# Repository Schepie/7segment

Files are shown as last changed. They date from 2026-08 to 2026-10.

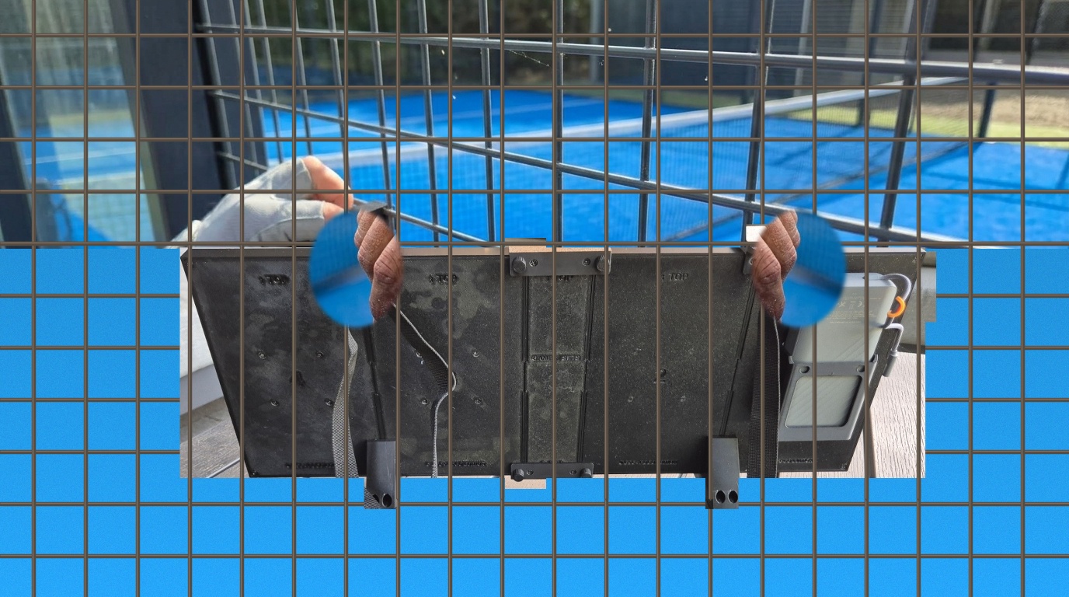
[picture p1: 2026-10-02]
scratch_hanging_proposal.jpg

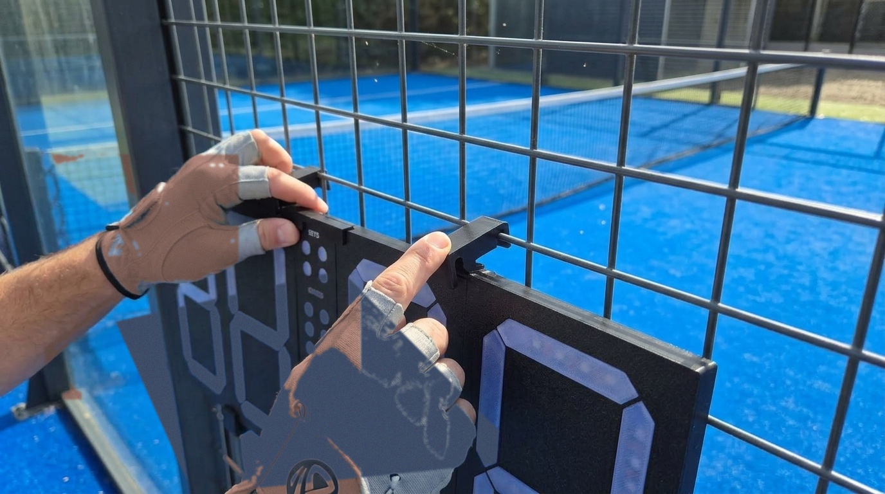
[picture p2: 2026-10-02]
scratch_hang_test.jpg

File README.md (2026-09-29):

# 🎾 ESP32 7-Segment Padel Scoreboard & Digital Clock

A professional, modular, high-visibility electronic scoreboard and real-time clock system built with **ESP32**, **WS2813 addressable LEDs (dual-signal backup line, up to 136 LEDs)**, **Bluetooth Low Energy (BLE)**, **Web Bluetooth API**, and snap-fit 3D-printed 7-segment displays.

The scoreboard acts as the **Master Rules Engine** and single source of truth for the entire match ecosystem, synchronizing in real time with the **Wear OS smartwatch app**, a physical **Xiaomi Bluetooth clicker remote**, and the **companion spectator mobile web app**.

📊 **Interactive Development Presentation Deck:** Open [**`presentation.html`**](presentation.html) in your browser (or view the [Presentation Notes](PRESENTATION.md)) for an interactive slide-by-slide walkthrough detailing how the hardware, 3D CAD, firmware SPI DMA drivers, and companion web apps were built.

---

## 🌟 System Architecture & Master/Slave Model

In this ecosystem, the **ESP32 Scoreboard is ALWAYS the Master**. It maintains and enforces all match rules, points, games, sets, and tiebreaks:

```
                  ┌─────────────────────────────────────────────────────────┐
                  │                 ESP32 SCOREBOARD MASTER                 │
                  │   (src/main_button_Setsandmatch.cpp / NVS Flash Cfg)    │
                  └───────────────┬─────────────────────────┬───────────────┘
                                  │                         │
                  BLE GATT Server │                         │ BLE Central (HID)
          ("Padel Display" 0x4FAF)│                         │ (Auto-Pairing)
                                  ▼                         ▼
         ┌─────────────────────────────────┐       ┌────────────────────────┐
         │     WEAR OS SMARTWATCH SLAVE    │       │  XIAOMI SHUTTER REMOTE │
         │   • Syncs rules via CMD,REQ     │       │    (XYLY01 Clicker)    │
         │   • Touch & voice point scoring │       │  • Big Btn: Team 1 (Pt)│
         │   • NFC & QR spectator sharing  │       │  • Sml Btn: Team 2 (Pt)│
         └────────────────┬────────────────┘       │  • Dbl Click: UNDO     │
                          │                        └────────────────────────┘
                          │ HTTPS REST
                          │ (Netlify Functions)
                          ▼
         ┌─────────────────────────────────┐
         │     SPECTATOR WEB APP SLAVE     │
         │   (https://padelpunten.netlify) │
         │   • Real-time match observer    │
         │   • Read-only rules display     │
         │   • Single Team Focus modes     │
         └─────────────────────────────────┘
```

* **Master Rules Enforcement:** Match rules (Golden Point vs. Advantage, Best of 3 sets vs. 1 set, 6 vs. 9 games per set, Tiebreak) are stored in ESP32 Non-Volatile Flash (`NVS`) and transmitted to clients on connect via `CFG,...`. Clients cannot alter rules during play.
* **Slave Synchronization:** The Wear OS app and spectator web app act as clients. They receive configuration broadcasts and mirror the official master state.
* **Web Bluetooth Direct Control:** Court administrators can configure match rules, brightness, sleep timeouts, and RTC time directly via the [Scoreboard Mobile Controller](https://schepie.github.io/7segment/settings.html).

---

## 🎨 Unified Team Color Standard

To avoid confusion between players, spectators, and hardware displays, all components adhere strictly to this unified color mapping:

| Component | Team 1 (Left / Serving) | Team 2 (Right / Receiving) | Sets Indicator |
| :--- | :---: | :---: | :---: |
| **Color** | **BLUE** | **RED** | **GOLD / YELLOW** |
| **ESP32 WS2813 RGB** | `RGB(0, 180, 255)` | `RGB(255, 0, 0)` | `RGB(255, 180, 0)` |
| **Web Controller (`settings.html`)** | `#00d2ff` | `#ff3366` | `#ffb300` |
| **Wear OS Watch App** | `#1E88E5` | `#E53935` | `#FFB300` |
| **Spectator Mobile Web App** | `#3b82f6` | `#ef4444` | `#eab308` |
| **Xiaomi Remote Button** | **Big Button (Top / Shutter)** | **Small Button (Bottom / Mode)** | N/A |
| **Physical Display Position** | **Digits 0 & 1 (Left)** | **Digits 2 & 3 (Right)** | **Middle Module (LEDs 56..79)** |

---

## 📖 Firmware Editions & Programs

All firmware source files reside in [`src/`](src/) and can be compiled using PlatformIO:

### 1. Flagship: Sets & Match Dual-Role Edition — [src/main_button_Setsandmatch.cpp](src/main_button_Setsandmatch.cpp) *(Recommended)*
The ultimate tournament firmware with simultaneous multi-device connectivity and dedicated Games & Sets indicators:
* **Simultaneous Connections:** Operates as a **BLE Central** (connected to the Xiaomi Remote clicker) **AND** a **BLE Peripheral** (advertising as `"Padel Display"` for the Wear OS watch and web controller).
* **24-LED Games & Sets Module (LEDs 56..79):**
  * Left column (Team 1 Blue): 9 Game LEDs (bottom-to-top) + 2 Set LEDs.
  * Right column (Team 2 Red): 2 Set LEDs + 9 Game LEDs (top-to-bottom).
* **Hardware SPI DMA Driver (ESP32-C3):** Pushes WS2813 bitstreams via hardware SPI MOSI (`GPIO 2`) with DMA buffering. Completely immune to BLE radio interrupts, preemption, or flicker. Features >= 280us LOW reset pulse timing and dual-signal line compatibility.
* **NVS Flash Persistence (`padel_cfg`):** Remembers match settings, LED brightness, idle timeouts, and paired remote MAC across power cuts.
* **Inactivity Idle Timer:** Automatically fades to Digital Clock mode after a configurable idle period (e.g. 5 minutes without activity).
* **Official Rules Engine:**
  * Advantage (`Ad`) vs. Golden Point / Punto de Oro (`GP`).
  * Sets to win (1 or 2).
  * Games per set (6 or 9).
  * Tiebreak mode at 6-6 (or 8-8) with alternating court side-swap tracking.
  * 30-step historical Undo buffer.
* **End-of-Match Celebration:** Victory animations (`GAmE`) and automated cycling through past set scores (`6-4`, `3-6`, `7-6`).

### 2. Unified 3-in-1 Firmware — [src/main_combined.cpp](src/main_combined.cpp)
Cycle between 3 distinct modes using a single onboard push-button (**BOOT** button on `GPIO 9` or `GPIO 0`):
* **Mode 0: Digital Clock (`CLOC`):** Displays 24-hour real-time clock synced via DS1302 RTC or computer build time.
* **Mode 1: BLE Padel Scoreboard (`SCOR`):** Standard BLE GATT server.
* **Mode 2: Xiaomi Shutter Remote Scoreboard (`ShUt`):** Direct BLE Central clicker connection.

### 3. Standalone Programs
* **[src/main_clock.cpp](src/main_clock.cpp):** Lightweight dedicated digital wall clock with smooth 6-second color crossfades.
* **[src/main.cpp](src/main.cpp):** Dedicated BLE GATT peripheral receiver.
* **[src/main_button.cpp](src/main_button.cpp):** Standalone Xiaomi remote clicker receiver (4 digits only).
* **[src/main_dual_4digits.cpp](src/main_dual_4digits.cpp):** Simultaneous remote + BLE watch connection without middle LED module.

---

## 📱 Web Bluetooth Controller & Settings App

Control the scoreboard directly from any smartphone, tablet, or laptop browser (Chrome, Edge, Bluefy) without installing an app:

🔗 **Live Controller URL:** [https://schepie.github.io/7segment/settings.html](https://schepie.github.io/7segment/settings.html)

### Features:
1. **Court Tab:** Live mirrored score digits, quick scoring buttons (+1 Team 1 Blue, +1 Team 2 Red), Undo, Reset Match, Court Side Swap, and Mode Switch (Clock / Scoreboard).
2. **Display Tab:** Real-time brightness slider (0..255), auto-sleep / idle timeout selector (Never, 1m, 5m, 10m, 15m, 30m), and one-tap **Sync Phone Time** button (sets the DS1302 RTC to local browser time).
3. **Rules Tab (Master Config):** Set Golden Point, Sets to Win (1 vs 3), Games per Set (6 vs 9), and Tiebreak rules. Automatically saves to ESP32 Flash memory and notifies connected smartwatches.
4. **Offline PWA Support:** Add to your mobile home screen with high-resolution icons for instant court-side launching.

---

## 📷 Xiaomi / YI Bluetooth Remote Controls (XYLY01)

The scoreboard connects directly to the Xiaomi / YI Action Camera Remote (`XiaoYi_RC`) over BLE HID (Characteristic `0x2A4D` under Service `0x1812`).

```
           ┌────────────────────────┐
           │        (  ○  )         │  <--- BIG BUTTON (0x40)
           │      Top Shutter       │       • Single Click: +1 Point Team 1 (Left / Blue)
           │                        │       • Double Click: UNDO Previous Point
           │                        │
           │        [  ■  ]         │  <--- SMALL BUTTON (0x80)
           │      Bottom Mode       │       • Single Click: +1 Point Team 2 (Right / Red)
           │                        │       • Double Click: UNDO Previous Point
           └────────────────────────┘
```

* **Single Click:**
  * **Big Button:** Adds a point to **Team 1 (Blue)** (` 0` $\to$ `15` $\to$ `30` $\to$ `40` $\to$ `Ad` $\to$ Game Won).
  * **Small Button:** Adds a point to **Team 2 (Red)**.
* **Double Click (Either Button within 380ms):**
  * Reverts the match state to the previous point, game, or set from the 30-entry history stack.
* **Auto-Pairing:** The ESP32 scans for `XiaoYi_RC`, pairs automatically, and persists the MAC address to NVS flash for instant reconnects on startup.

---

## 📡 Bluetooth Low Energy (BLE) Protocol Specification

The ESP32 runs a BLE GATT Server advertising as `"Padel Display"`.

### GATT Identifiers:
* **Device Name:** `Padel Display`
* **GATT Service UUID:** `4fafc201-1fb5-459e-8fcc-c5c9c331914b`
* **GATT Characteristic UUID:** `beb5483e-36e1-4688-b7f5-ea07361b26a8`
* **Client Characteristic Configuration (CCCD):** `00002902-0000-1000-8000-00805f9b34fb` (Enable notifications: `0x0001`)

### Packet Formats:

#### 1. Configuration Broadcast (`CFG,...`)
Sent automatically upon client connection, or in response to `CMD,REQ_CFG`:
```
"CFG,GP=0,SETS=2,GAMES=6,TB=1,BRT=180,IDLE=300000"
      │    │      │       │    │       └── Inactivity idle timeout in ms (300000 = 5 min)
      │    │      │       │    └────────── LED Brightness (0 - 255)
      │    │      │       └─────────────── Tiebreak Enabled (1 = Yes, 0 = No)
      │    │      └─────────────────────── Games per Set (6 or 9)
      │    └────────────────────────────── Sets to Win (1 = Single set, 2 = Best of 3)
      └─────────────────────────────────── Golden Point (1 = Punto de Oro, 0 = Advantage)
```
Clients can write this string to update and persist rules into ESP32 flash.

#### 2. Live Score Notification (`SCORE,...`)
Notified whenever points, games, sets, or court sides change:
```
"1530,0,1,2,0,0,0"
 │ │ │ │ │ │ │ └── In Tiebreak Mode (0 = Normal, 1 = Tiebreak active)
 │ │ │ │ │ │ └──── Team 2 Sets Won
 │ │ │ │ │ └────── Team 1 Sets Won
 │ │ │ │ └──────── Team 2 Games Won
 │ │ │ └────────── Team 1 Games Won
 │ │ └──────────── Court Side Swapped Flag (0 = Normal, 1 = Swapped ends)
 │ └────────────── Team 2 Points (" 0", "15", "30", "40", "Ad")
 └──────────────── Team 1 Points (" 0", "15", "30", "40", "Ad")
```
*In Tiebreak mode*, points represent tiebreak rally points: `" 4 3,0,6,6,1,1,1"`.

#### 3. Control Commands (`CMD,...`)
Written by clients (Watch or Web Controller) to trigger actions:
* `CMD,P1`: Increment point for Team 1 (Blue).
* `CMD,P2`: Increment point for Team 2 (Red).
* `CMD,UNDO`: Step back one state in history.
* `CMD,RESET`: Reset the match to 0-0.
* `CMD,SWAP`: Manually toggle court side display orientation.
* `CMD,CLOCK`: Force the display into Digital Clock mode.
* `CMD,SCORE`: Wake up display into Scoreboard mode.
* `CMD,REQ` / `CMD,REQ_CFG`: Request the ESP32 to immediately notify current configuration and score.

#### 4. Time Synchronization (`TIME,...`)
Written by `settings.html` to calibrate the onboard DS1302 RTC:
```
"TIME,14:35:00"
```

---

## 🔌 Hardware Wiring & Pinout

### 1. LED Chain Routing (136 LEDs Total)
One continuous data line connects all modules in series:

```
ESP32 DIN (GPIO 2) ──> [ Digit 0 ] ──> [ Digit 1 ] ──> [ Games & Sets ] ──> [ Digit 2 ] ──> [ Digit 3 ]
                       (28 LEDs)       (28 LEDs)       (24 LEDs)            (28 LEDs)       (28 LEDs)
                       LEDs 0..27      LEDs 28..55     LEDs 56..79          LEDs 80..107    LEDs 108..135
                       Team 1 Tens     Team 1 Ones     Middle Module        Team 2 Tens     Team 2 Ones
```

### 2. Segment Wiring per Digit (4 LEDs $\times$ 7 segments = 28 LEDs)
* **Standard Digits (Digits 1, 2, 3):**
  * Segment 0 (BL - Bottom-Left): LEDs `0..3`
  * Segment 1 (B  - Bottom): LEDs `4..7`
  * Segment 2 (BR - Bottom-Right): LEDs `8..11`
  * Segment 3 (M  - Middle): LEDs `12..15`
  * Segment 4 (TL - Top-Left): LEDs `16..19`
  * Segment 5 (T  - Top): LEDs `20..23`
  * Segment 6 (TR - Top-Right): LEDs `24..27`
* **Digit 0 Hardware Variation (`PANEL0_CUSTOM_WIRING`):**
  * Handled automatically in firmware mapping (`panel0SegmentMap`): Slot 0=`TR`, Slot 1=`T`, Slot 2=`TL`, Slot 3=`M`, Slot 4=`BR`, Slot 5=`B`, Slot 6=`BL`.

### 3. Games & Sets Indicator Module (LEDs 56..79)
* **Left Column (Team 1 Blue, bottom to top):**
  * LEDs 56..64 (Indices 0..8): Games G1..G9
  * LED 65 (Index 9): Blank spacer
  * LEDs 66..67 (Indices 10..11): Sets S1..S2
* **Right Column (Team 2 Red, top to bottom):**
  * LEDs 68..69 (Indices 12..13): Sets S2 (top) & S1 (lower)
  * LED 70 (Index 14): Blank spacer
  * LEDs 71..79 (Indices 15..23): Games G9 down to G1

### 4. Microcontroller Pinout Table (ESP32-C3 SuperMini)

| Function | ESP32-C3 SuperMini Pin | Description |
| :--- | :---: | :--- |
| **WS2813 DIN Data Pin** | **`GPIO 2`** | Hardware SPI MOSI (high speed, accurate WS2813 timing) |
| **Status LED** | `GPIO 8` | Blue Onboard LED (Active LOW) |
| **Mode / Boot Button** | `GPIO 9` | Onboard Button / External score control |
| **RTC DS1302 CLK (SCLK)** | `GPIO 4` | Clock line for DS1302 Real-Time Clock module |
| **RTC DS1302 DAT (I/O)** | `GPIO 5` | Bi-directional data line for DS1302 |
| **RTC DS1302 RST (CE)** | `GPIO 3` | Chip enable / reset line for DS1302 |

---

## ⚡ Building & Uploading (PlatformIO)

The project targets the ESP32-C3 SuperMini configured in [`platformio.ini`](platformio.ini):

| Target Microcontroller | Firmware Feature Set | PlatformIO Environment |
| :--- | :--- | :--- |
| **ESP32-C3 SuperMini** | **Flagship (Sets & Match + Module)** | `esp32c3_supermini_button` |

### CLI Build & Flash:
```powershell
# Build and upload flagship firmware to ESP32-C3 SuperMini
pio run -e esp32c3_supermini_button -t upload

# Monitor serial output at 115200 baud
pio device monitor -b 115200
```

---

## 🖨️ 3D Printing Assets (`/scad`)

All enclosure, digit, bracket, and mounting files are open-source OpenSCAD designs:
* `panel_thumbscrew.scad`: **Tool-free M3 thumbscrew knob system** (ergonomic knurled finger knob with anti-spin hex drive lock for M3x12 DIN 7991 countersunk screws and 3.0 mm panel heat-set inserts; 11.2 mm outer diameter engineered specifically for 12.0 mm seam bracket pitch without knob collisions; 100% support-free).
* `display_stand.scad`: **Direct-Mount Desktop Cradle Stand & Seam U-Bracket Replacement** (engineered tabletop stand system with ergonomic 8° backward viewing tilt, compact footprint, and 2x 13.0 mm anti-slip rubber pad recesses; 100% support-free 3D printing):
  * **Direct Panel Mounting (Replaces Bottom U-Bracket):** Standardized to 28.0 mm width with 2x M3 pass-through clearance holes (12.0 mm pitch, 6.0 mm rim inset) drilled directly through the rear spine into the panel backplates' brass heat-set inserts. Because the stand grips both the front lip (11.5 mm) and bolts into the rear backplate, it acts as a rigid bottom U-channel clamping bracket across digit seams ([Digit 1 + Digit 2] or [Digit 3 + Digit 4]), permanently eliminating joint bending while serving as the tabletop foot.
  * **Flush Fastening & Tool Access:** Features DIN 7991 countersink seats (3.2 mm flange thickness matching bracket hardware) and Ø 8.5 mm rear counterbore wells for direct hex-key and screwdriver tool access.
  * **Bolt-on Kickstand Legs:** Alternate rear triangular kickstand legs (`part=4`, `part=5`) for ultra-minimalist prop-up display.
  * STLs: `3d_models/display_stand_cradle_single.stl`, `3d_models/display_stand_cradle_pair.stl`.
* `rear_corner_foot.scad`: Outer corner leveling foot (3.0 mm) ensuring flush, wobble-free table placement across joined rear brackets.
* `rear_joining_bracket_hinged.scad`: Heavy-duty hinged panel-to-panel joining bracket with 3D-printable snap pin (0° to 180° folding).
* `7segment_pogo.scad`: Modular 7-segment digit housings with integrated magnetic pogo pin pockets, diffuser slots, and VESA 50x50 mounts.
* `remote_strap_holder.scad`: Ergonomic clip for wearing the Xiaomi Shutter remote on a wristband or racket lanyard.
* `games_sets_u_bracket.scad`: **Unified 3-Panel U-Profile Bridge Bracket** (continuous 84 mm rigid bridge spanning across the central Games & Sets module and both adjacent digits; U-profile channel clamps both the front face and rear backplate across all 4 M3 corner screw positions to permanently eliminate joint flexing and bending; integrated front-lip cutout provides full clearance for the frontplate "SETS" text; 100% support-free 3D printing; fits both top and bottom rims).
  * STLs: `3d_models/games_sets_u_bracket.stl`, `3d_models/games_sets_u_bracket_pair.stl`.
* `panel_seam_u_bracket.scad`: **2-Panel Digit Seam U-Profile Joining Bracket, Padel Court Hook & Carrying Strap Mount** (rigid 28 mm U-channel bracket clamping across adjacent 7-segment digit panels [Digit 1 + Digit 2] or [Digit 3 + Digit 4] on a 12.0 mm screw pitch; straight square top corners):
  * **Standard Clean U-Bracket** (`part=1`, `part=2`): Clamps top or bottom seam with zero support needed.
  * **Padel Mesh Hook with Top-Facing Strap Eye** (`part=3`, `part=4`, `part=5`): Features the front-facing wire mesh hook (Ø 5.6 mm throat, 16 mm retention lip, 45° entry mouth) with the monolithic triangular carrying strap eye extending vertically upwards from the roof.
  * **Padel Mesh Hook with Rear-Facing Strap Eye** (`part=6`, `part=7`, `part=8`): Features the strap eye extending horizontally **from the back** of the bracket (with dual 45° transition tapers), leaving the top roof 100% flat. The bottom taper terminates at Y = 0 mm, leaving the entire rear flange (Y = 0 to 17 mm) completely flat and open with >6 mm of clearance above the M3 screw centers for effortless screwdriver and Allen key access. Prints flat on its side with 100% continuous perimeter loops and zero support.
  * STLs: `3d_models/panel_seam_u_bracket.stl`, `3d_models/panel_seam_u_hook_bracket.stl`, `3d_models/panel_seam_u_hook_bracket_pair.stl`, `3d_models/panel_seam_u_hook_bracket_rear_eye.stl`, `3d_models/panel_seam_u_hook_bracket_rear_eye_pair.stl`, `3d_models/panel_seam_u_bracket_set4_hook.stl`.
* `games_sets_pogo_snap_individual_dots.scad`: Middle module housing for the 24-LED column array.

---

## 👤 Author
**Geert Schepers**

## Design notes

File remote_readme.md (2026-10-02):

# Xiaomi / YI Bluetooth Remote (XYLY01) Integration Manual

This document details the hardware configuration, Bluetooth Low Energy (BLE) HID communication protocol, button mapping, and 7-segment display driver settings for the **Xiaomi / YI Action Camera Remote (Model: XYLY01 / XiaoYi_RC)** communicating with an **ESP32-C3 SuperMini**.

---

## 1. Hardware Specifications

| Component | Specification |
| :--- | :--- |
| **Microcontroller** | ESP32-C3 SuperMini (RISC-V 160MHz, 4MB Flash, USB CDC on boot) |
| **Bluetooth Remote** | Xiaomi / YI Remote (Model: `XYLY01`, Advertised Name: `XiaoYi_RC`) |
| **Display Panel** | 2x Chained 7-Segment Modules (56 WS2813 LEDs total: 2 digits $\times$ 7 segments $\times$ 4 LEDs) |
| **WS2813 DIN Pin** | **`GPIO 2`** |
| **Onboard Status LED** | **`GPIO 8`** (ESP32-C3 SuperMini onboard LED, active LOW) |
| **LED Index Offset** | **`+1 LED`** (`#define LED_START_OFFSET 1`) for mechanical alignment inside diffusers |

---

## 2. PlatformIO Board Configuration (`platformio.ini`)

The ESP32-C3 SuperMini environment in `platformio.ini`:

```ini
[env:esp32c3_supermini_button]
platform = espressif32
board = esp32-c3-devkitm-1
framework = arduino
build_flags = 
	-DARDUINO_USB_CDC_ON_BOOT=1
	-DARDUINO_USB_MODE=1
lib_deps = 
	adafruit/Adafruit NeoPixel
	h2zero/NimBLE-Arduino @ ^1.4.2
	makuna/RTC @ ^2.4.3
```

---

## 3. BLE HID Communication & Protocol (NimBLE)

### A. Discovery & Identification
- **Supported Remotes:**
  - **Xiaomi / YI Remote (XYLY01):** Advertised Name `XiaoYi_RC`, `XYLY01`
  - **WXLJ-02 & Bluetooth Ring Remotes:** Advertised Names `WXLJ-02`, `WXLJ`, `D01`, `D02`, `Ring`, `Turner`, `Scroller`, `Beauty`
  - **Generic BLE HID Peripherals:** Any BLE peripheral advertising Service UUID `0x1812` or HID Appearance (`0x03C0..0x03C4`).
- **Target Remote MAC Address:** Stored in persistent flash (`padel_remote/remote_mac`) after first pairing for instant auto-reconnect.

### B. Security & Connection Parameters
- The remote operates with **Just Works / Auto-confirm** bonding:
  ```cpp
  NimBLEDevice::init("Padel Display");
  NimBLEDevice::setSecurityAuth(true, true, true); // Bonding + MITM + Secure Connections
  NimBLEDevice::setSecurityIOCap(BLE_HS_IO_NO_INPUT_OUTPUT);
  NimBLEDevice::setPower(ESP_PWR_LVL_P9);
  ```
- **Connection Timing (Prevent Dropouts):**
  ```cpp
  bleClient->setConnectionParams(24, 40, 0, 400); // 30ms - 50ms interval, 4s supervision timeout
  ```
- **Subscribing to HID Notifications:**
  Subscribe to all characteristics with `canNotify()` or `canIndicate()` under Service `0x1812` (particularly Report Characteristic `0x2A4D`) with `pChar->subscribe(true, onHIDNotification, true)`.

---

## 4. Remote Button Packet Structure (XYLY01)

The remote transmits **3-byte notification payloads** to Characteristic `0x2A4D`:

| Button / Action | Raw Notification Bytes | Logic State | Action Triggered |
| :--- | :--- | :--- | :--- |
| **Big Button (Top / Shutter)** | `0x40 0x00 0x00` | Pressed | **Count UP (+1)** |
| **Small Button (Bottom / Mode)** | `0x80 0x00 0x00` | Pressed | **Count DOWN (-1)** |
| **Button Release** | `0x00 0x00 0x00` | Released | Evaluates click count & timing |

---

## 4.B WXLJ-02 & Ring Remote Button Mapping

The WXLJ-02 Bluetooth ring remote features a 3-button layout (Up / Center / Down):

| Button | Supported HID Codes | Scoreboard Function |
| :--- | :--- | :--- |
| **▲ Up Button** | Up Arrow (`0x52`), Page Up (`0x4B`), Volume Up (`0xE9`), Next Track (`0xB5`) | **+1 Point Team 1 (Left / Blue)** |
| **▼ Down Button** | Down Arrow (`0x51`), Page Down (`0x4E`), Volume Down (`0xEA`), Prev Track (`0xB6`) | **+1 Point Team 2 (Right / Red)** |
| **● Center Button** | Return/Enter (`0x28`), Space (`0x2C`), Play/Pause (`0xCD`), Mute (`0xE2`) | **Instant UNDO** (during match)<br>• **Toggle 1st Server** (at 0–0)<br>• **Wake up** (from Clock Mode) |
| **Double Click (▲/▼)** | Within 380ms | **Instant UNDO / Toggle Server** |
| **Long Press (≥1.5s)** | Hold either directional button | **Swap Court Sides** / Toggle Clock |

---

## 5. Interaction & Scoring Controls

```
           ┌────────────────────────┐
           │        (  ○  )         │  <--- BIG BUTTON (0x40)
           │      Top Shutter       │       • Single Click: Count UP (+1)
           │                        │       • Double Click: Next Color
           │                        │
           │        [  ■  ]         │  <--- SMALL BUTTON (0x80)
           │      Bottom Mode       │       • Single Click: Count DOWN (-1)
           │                        │       • Double Click: Next Color
           └────────────────────────┘
```

- **Single Click:**
  - **Big Button:** Increases score from $1 \to 99$.
  - **Small Button:** Decreases score from $99 \to 1$.
- **Double Click (Either Button):**
  - Detected within a **`380ms`** window.
  - Cycles through 8 curated color presets:
    1. Cyan / Ice Blue (`0, 220, 255`)
    2. Vivid Red (`255, 0, 0`)
    3. Emerald Green (`0, 255, 60`)
    4. Sunset Orange (`255, 75, 0`)
    5. Golden Yellow (`255, 200, 0`)
    6. Electric Purple (`180, 20, 255`)
    7. Pure White (`255, 255, 255`)
    8. Hot Pink (`255, 20, 150`)
- **Visual Feedback:**
  - Double-clicking flashes the new color twice on the display for immediate confirmation.

---

## 6. Onboard Status LED (GPIO 8)

The onboard status LED on GPIO 8 indicates connectivity states:
- **Blinking:** Booting, scanning, or awaiting Bluetooth connection.
- **Solid ON:** Successfully connected to remote / app and actively receiving scores.
- **OFF:** Idle or disconnected.

---

## 7. 7-Segment Wiring & Offsets

```cpp
#define LED_PIN           2      // ESP32-C3 SuperMini GPIO 2
#define NUM_DIGITS        2      // 2 Digits
#define LEDS_PER_SEGMENT  4      // 4 LEDs per segment
#define LEDS_PER_DIGIT    28     // 7 segments * 4 = 28 LEDs per digit
#define LED_START_OFFSET  1      // +1 LED shift to align physical channels
#define NUMPIXELS         (NUM_DIGITS * LEDS_PER_DIGIT + LED_START_OFFSET)
```

### Segment Wiring Order:
- `Seg A`: Bottom-Left ($0 \to 3$)
- `Seg B`: Bottom ($4 \to 7$)
- `Seg C`: Bottom-Right ($8 \to 11$)
- `Seg D`: Middle ($12 \to 15$)
- `Seg E`: Top-Left ($16 \to 19$)
- `Seg F`: Top ($20 \to 23$)
- `Seg G`: Top-Right ($24 \to 27$)

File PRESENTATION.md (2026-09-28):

# 🎾 Development of the 7-Segment Padel Scoreboard & Apps Ecosystem
## Engineering Presentation & Slide Notes

> **Interactive Presentation Deck:** Open [`presentation.html`](presentation.html) in any modern browser for full-screen slide transitions, keyboard controls (`←`/`→`/`Space`), speaker notes (`N`), slide overview grid (`O`), and an embedded interactive score simulator.

---

### Slide 1: System Architecture & Vision
**Title:** ESP32 7-Segment Padel Scoreboard & Digital Clock  
**Category:** System Architecture & Vision

- **The Problem:** Padel rallies are fast-paced, high-intensity, and often result in disputes over points, games, and court side swaps. Existing commercial scoreboards are bulky, fragile, expensive ($500+), or require manual turning.
- **The Solution:** A high-visibility 136-LED scoreboard built with **WS2813 addressable LEDs** (featuring a dual-signal backup data line to prevent cascade dropouts), where the **ESP32 microcontroller is always the Master** and single source of truth. Dual-role Bluetooth Low Energy (BLE) connects directly to an on-racket Xiaomi clicker, Wear OS smartwatches, and a zero-install mobile web controller.
- **Dual Mode:** When idle for a configurable period (e.g., 5 minutes), the display smoothly crossfades into an ambient 24-hour digital wall clock driven by a DS1302 RTC chip.

---

### Slide 2: Phase 1 — Mechanical & 3D CAD Engineering (OpenSCAD)
**Title:** Modular OpenSCAD Parametric Design  
**Category:** Phase 1 • Mechanical Engineering

- **Parametric 7-Segment Digit Housings (`7segment_pogo.scad`):**
  - Light-isolation diffuser channels preventing light bleed between adjacent segments.
  - 4 LEDs per segment (28 LEDs per digit), perfectly scaled for 20+ meter court visibility.
  - Pogo-pin and magnetic side pockets enabling solderless daisy chaining.
- **Central Games & Sets Module (`games_sets_pogo_snap_individual_dots.scad`):**
  - 24 addressable LEDs in a dual-column vertical ladder.
  - Left column: Team 1 (Blue) Games 1–9 + Sets 1–2.
  - Right column: Team 2 (Red) Sets 1–2 + Games 9–1.
- **The Padel Court Mesh Hook Bracket (`panel_seam_u_hook_bracket.scad`):**
  - **Ball Impact Engineering:** Rather than hanging the display inside the court where smash balls hit at 120+ km/h, the U-profile hook suspends the scoreboard *safely behind* the court's 50x50 mm steel wire fence.
  - The fence wire absorbs all impact kinetic energy while the LEDs shine through the wire openings.
- **Desktop 8° Tilt Cradle Stand (`display_stand.scad`):**
  - Dual M3 direct-mount pass-through bolting directly into panel backplate brass inserts, eliminating joint flex.

---

### Slide 3: Phase 2 — Electronics, Wiring & Power Topologies
**Title:** LED Serial Bus & Microcontroller Hardware  
**Category:** Phase 2 • Electronics & Power Topologies

- **Continuous 136-LED Serial Data Stream:**
  ```
  ESP32 DIN (GPIO 2) ──> [ Digit 0 ] ──> [ Digit 1 ] ──> [ Games & Sets ] ──> [ Digit 2 ] ──> [ Digit 3 ]
                         (28 LEDs)       (28 LEDs)       (24 LEDs)            (28 LEDs)       (28 LEDs)
  ```
- **Microcontroller Pinout (ESP32-C3 SuperMini):**
  - Hardware SPI MOSI on `GPIO 2`, status LED on `GPIO 8`, DS1302 RTC on `GPIO 4 / 5 / 3`.
- **Panel 0 Custom Segment Translation (`panel0SegmentMap`):**
  - Mechanical symmetry required reversing the ribbon connector on Digit 0. Firmware remaps the hardware order to logical segments in constant time.
- **DS1302 Real-Time Clock:**
  - Onboard coin-cell backup ensures accurate timekeeping across court power interruptions.

---

### Slide 4: Phase 3 — The Critical Firmware Breakthrough: Hardware SPI DMA vs. BLE
**Title:** The Critical Breakthrough: Hardware SPI DMA vs. BLE  
**Category:** Phase 3 • Embedded Firmware Engineering

- **The Real-World Failure (Neopixel Bit-Banging):**
  - Standard libraries (Adafruit NeoPixel) use cycle-counted software loops to generate the 800 kHz LED waveform.
  - In our dual-role architecture, the ESP32 BLE radio generates frequent high-priority hardware interrupts.
  - **Symptom:** High BLE transmission rates corrupted the bit-bang timing, causing random flashes, color tearing, and dropped frames.
- **The Engineering Solution (Hardware SPI DMA):**
  - Replaced bit-banging with the **ESP32-C3 Hardware SPI MOSI peripheral with Direct Memory Access (DMA)**.
  - WS2813 bits are converted into a DMA bit buffer and transferred to `GPIO 2` by hardware silicon.
  - **Zero CPU overhead and 100% immunity to BLE interrupts**, delivering flicker-free LED animations.
- **Why WS2813 & Reset Pulse Compensation:**
  - **Dual-Signal Line:** WS2813 features a backup data line (`BIN`), ensuring that if any single LED fails, the signal bypasses it without breaking the rest of the display.
  - **Reset Timing:** WS2813 chips require a >280 µs reset pulse (compared to 50 µs on older LEDs). We padded the DMA transmission frame with trailing zeros to guarantee clean frame latching.

---

### Slide 5: Phase 4 — Master Rules Engine & State Machine
**Title:** The Scoreboard is Always the Master  
**Category:** Phase 4 • Embedded Logic & Rules Engine

- **The Master/Slave Model:**
  - All match rules, points, games, sets, and side swaps are computed exclusively on the ESP32.
  - Clients (Wear OS watches, web apps) are pure displays and control inputs. They cannot overwrite rules during play.
- **Official Padel Logic:**
  - Golden Point (*Punto de Oro*) vs. Advantage (`Ad`).
  - Sets to win (1 or 2; best of 3).
  - Games per set (6 or 9).
  - Tiebreak mode at 6–6 (or 8–8) with white `tb` and `Stb` (Super Tiebreak) badges.
- **30-Step Historical Undo Stack:**
  - Every point change pushes full match state onto a circular ring buffer.
  - Double-clicking either button on the remote or tapping Undo instantly reverts erroneous points.
- **Non-Volatile Storage (NVS Flash):**
  - Rules, brightness, idle timeouts, and paired remote MAC addresses persist across power cycles.

---

### Slide 6: Phase 5 — Dual-Role BLE & Protocol Specification
**Title:** Dual-Role BLE Architecture & GATT Protocol  
**Category:** Phase 5 • Wireless Networking

- **Dual-Role Operation (NimBLE-Arduino):**
  - **BLE Central:** Scans and connects to the Xiaomi / YI Shutter Remote (XYLY01) over HID Service `0x1812`.
  - **BLE Peripheral:** Advertises GATT Server `"Padel Display"` (UUID `0x4FAF`), handling connections from watches and web browsers.
- **Remote Button Mapping (XYLY01):**
  - Single Click Top Button (`0x40`): Team 1 (+1 Point)
  - Single Click Bottom Button (`0x80`): Team 2 (+1 Point)
  - Double Click (within 380 ms): Undo previous point
- **GATT Protocol (Characteristic `0xBEB5`):**
  - `SCORE,...`: Live scores notification (`"1530,0,1,2,0,0,0"`).
  - `CFG,...`: Configuration broadcast (`"CFG,GP=0,SETS=2,GAMES=6,TB=1,BRT=180,IDLE=300000"`).
  - `CMD,...`: Remote control commands (`CMD,P1`, `CMD,P2`, `CMD,UNDO`, `CMD,RESET`, `CMD,SWAP`, `CMD,CLOCK`).
  - `TIME,...`: Clock synchronization (`"TIME,14:35:00"`).

---

### Slide 7: Phase 6 — Mobile Web Controller PWA (`index.html`)
**Title:** Zero-Install Mobile Controller PWA  
**Category:** Phase 6 • Companion Web Application

- **Web Bluetooth API:**
  - Directly pairs with the ESP32 from Chrome, Edge, and iOS Bluefy without App Store or Play Store friction.
- **Three Core Tabs:**
  1. **Court Tab:** Live mirrored digits, large tactile score buttons, side swap, undo, and mode switch.
  2. **Display Tab:** Debounced brightness slider (0–255), auto-idle sleep timeout selector, and one-tap **Sync Phone Time**.
  3. **Rules Tab:** Configure Golden Point, sets, games, and tiebreak presets.
- **PWA Capabilities:**
  - Offline Service Worker (`sw.js`), Apple touch icons, and dark/light mode themes with instant anti-flash localStorage initialization.
- **BLE Write Debouncing:**
  - A 60 ms animation-frame throttle queue prevents rapid slider gestures from congesting the BLE connection.

---

### Slide 8: Phase 7 — Wear OS Companion & Spectator Ecosystem
**Title:** Wear OS Smartwatch & Spectator Web App  
**Category:** Phase 7 • Wearables & Cloud Spectators

- **Wear OS Smartwatch Companion:**
  - Designed for players preferring wrist scoring over racket remotes.
  - Touch interface with distinct haptic vibration pulses for points, game points, and set wins.
  - Queries master rules via `CMD,REQ` on connection.
- **Spectator Web Observer (`padelpunten.netlify.app`):**
  - External web app allowing clubhouse spectators to monitor ongoing matches via lightweight REST synchronization.
- **Unified Team Color Standard:**
  - Team 1: Electric Blue (`#00d2ff` / `RGB(0, 180, 255)`)
  - Team 2: Vivid Red (`#ff3366` / `RGB(255, 0, 0)`)
  - Sets & Ladder: Amber Gold (`#ffb300` / `RGB(255, 180, 0)`)

---

### Slide 9: Phase 8 — Wireless Browser-Based OTA Firmware Updates
**Title:** Wireless Browser-Based OTA Updates  
**Category:** Phase 8 • Maintenance & Field Deployments

- **The Problem:** Scoreboards mounted high on court walls or behind wire cages cannot be easily cabled via USB to a laptop.
- **The Solution:** A dedicated browser flasher (`ota.html`) communicating over Web Bluetooth.
- **Engineering Features:**
  - 512-byte chunked MTU packet slicing.
  - Dual ESP32 OTA partitions (`ota_0`, `ota_1`) with automated CRC validation and rollback protection.
  - Python CLI companion script (`scripts/ble_ota_flash.py`) for automated CI/CD flashing.

---

### Slide 10: Phase 9 — Interactive Showcase & Commercial Simulator
**Title:** Interactive Web Simulator & Showcase  
**Category:** Phase 9 • Commercialization & Virtual Testing

- **Purpose:** Prior to mass 3D printing and hardware assembly, `showcase.html` provided an interactive virtual playground.
- **Virtual Scoreboard & Racket Remote:**
  - Fully animated 7-segment digits, 24-LED ladder, and virtual clicker simulating single and double-click actions.
- **Market & Pricing Survey:**
  - Embedded feedback widget gathering player and court club feedback on DIY kits, pre-assembled packages, and price points.

---

### Slide 11: Phase 10 — Real-World Testing & Key Engineering Iterations
**Title:** Real-World Engineering Iterations  
**Category:** Phase 10 • Git History & Field Iterations

1. **Court Side Swap Inversion (`85f3d6f`):** Fixed bug where touch targets inverted relative to physical display orientation during end swaps.
2. **Tiebreak Badging (`067e33a`):** Added white `tb` and `Stb` badges so players know when points count rallies (1..7) instead of normal tennis points.
3. **Brightness Slider Flooding (`985b6fd`):** Debounced slider events to eliminate watchdog timeouts during rapid dragging.
4. **Ambient Clock Crossfading (`f2769cf`):** Added smooth 6-second color crossfade transitions for clubhouse clock mode.
5. **Racket Strap Mount (`285b92c`):** Created 3D printable racket lanyard and wrist strap holders to prevent clicker drops.
6. **Snap-Fit 3D Print Tolerances (`cbdffa0`):** Tuned 0.25 mm bead interferences for support-free diffuser snap-fitting.

---

### Slide 12: Architecture Summary & Future Roadmap
**Title:** Architecture Summary & Future Roadmap  
**Category:** Conclusion & Future Vision

- **Multidisciplinary Synergy:**
  - **Mechanical:** OpenSCAD parametric design, mesh hook protection, cradle stand.
  - **Embedded:** ESP32 C++, Hardware SPI DMA, NimBLE dual-role.
  - **Web Applications:** Web Bluetooth API, Service Worker PWA, OTA updates.
- **Future Roadmap:**
  - **ESP-NOW Court Mesh:** Interconnecting all court scoreboards to a master clubhouse tournament board.
  - **Voice-Activated Scoring:** Offline keyword spotting for hands-free scoring (*"Point Blue"*).
  - **Automated Video Highlights:** Remote double-click triggering timestamp bookmarks on court IP cameras.

---

## 🛠️ How to Present
- **To present directly in browser:** Open [`presentation.html`](presentation.html) and press `F` for Fullscreen.
- **To view speaker notes:** Press `N` to open the notes drawer.
- **To view slide thumbnail grid:** Press `O` or click the Overview button.
- **To print/export to PDF:** Use `Ctrl + P` (or `Cmd + P` on Mac) and choose "Save as PDF" — the stylesheet includes dedicated `@media print` rules for clean slide-per-page rendering.

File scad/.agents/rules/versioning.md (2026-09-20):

# Versioning Rule

## Always bump the version when editing `index.html`

Whenever `index.html` is modified, you **must** increment the patch version number in **both** of these files before finishing:

1. **`index.html`** — update `CURRENT_APP_VERSION`:
   ```js
   const CURRENT_APP_VERSION = '1.x.y';
   ```

2. **`version.json`** — update `version` and `notes`:
   ```json
   {
     "version": "1.x.y",
     "buildTime": "<ISO timestamp of change>",
     "notes": "<short description of what changed>"
   }
   ```

### Version format
Use **semver patch bumps** (`1.4.7` -> `1.4.8`) for regular changes.  
Use a **minor bump** (`1.4.x` -> `1.5.0`) only for significant new features.

Both files must always be **in sync** -- the same version string in both.

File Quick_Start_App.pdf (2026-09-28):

# Padel Scoreboard Mobile App

Web Bluetooth Controller & Live Spectator Hub • Quick Start Guide

PWA • SCHEPIE.GITHUB.IO/7SEGMENT

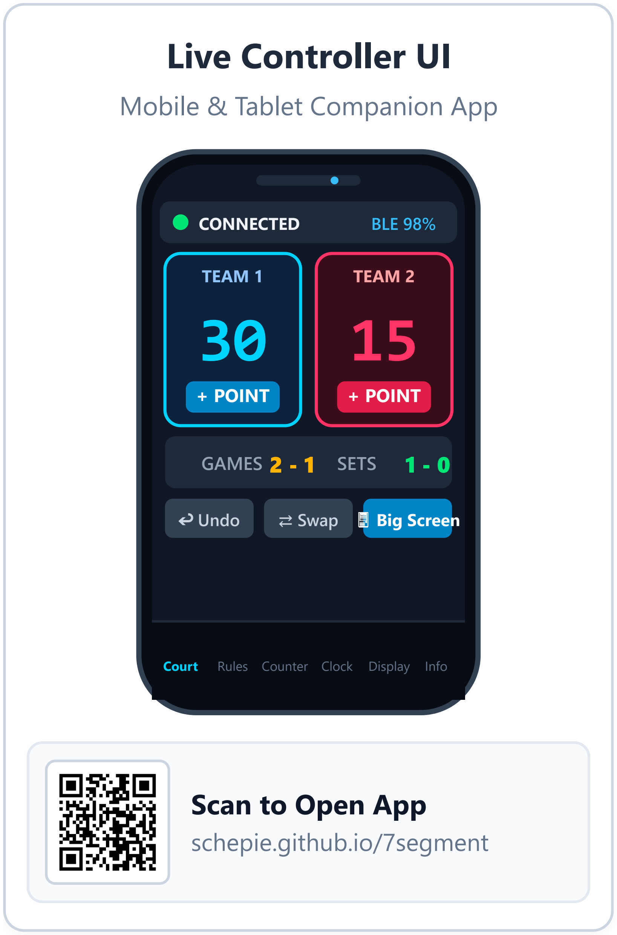
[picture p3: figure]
Live Controller UI; Mobile & Tablet Companion App; CONNECTED; BLE 98%; TEAM 1 30; + POINT; TEAM 2 15; GAMES 2 - 1 SETS 1 - 0; ↩ Undo; ⇄ Swap 🖥 Big Screen; Court Rules Counter Clock Display Info; Scan to Open App schepie.github.io/7segment

## App Tabs & Navigation Guide

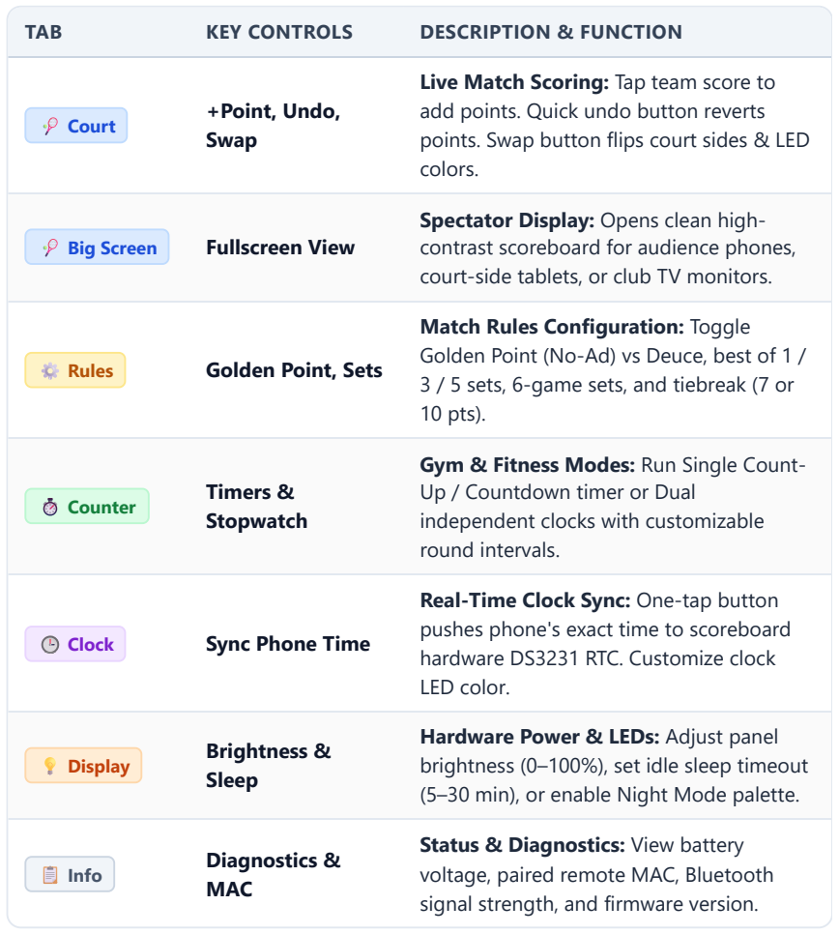
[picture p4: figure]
TAB; KEY CONTROLS; DESCRIPTION & FUNCTION; 🎾 Court; +Point, Undo, Swap; Live Match Scoring: Tap team score to add points. Quick undo button reverts; colors.; 🎾 Big Screen; Fullscreen View; Spectator Display: Opens clean high- contrast scoreboard for audience phones,; ⚙️ Rules; Golden Point, Sets; Match Rules Configuration: Toggle; 10 pts).; ⏱️ Counter; Timers & Stopwatch; Gym & Fitness Modes: Run Single Count- Up / Countdown timer or Dual independent clocks with customizable round intervals.; 🕒 Clock; Sync Phone Time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

points. Swap button flips court sides & LED

court-side tablets, or club TV monitors.

Golden Point (No-Ad) vs Deuce, best of 1 / 3 / 5 sets, 6-game sets, and tiebreak (7 or

brightness (0–100%), set idle sleep timeout (5–30 min), or enable Night Mode palette.

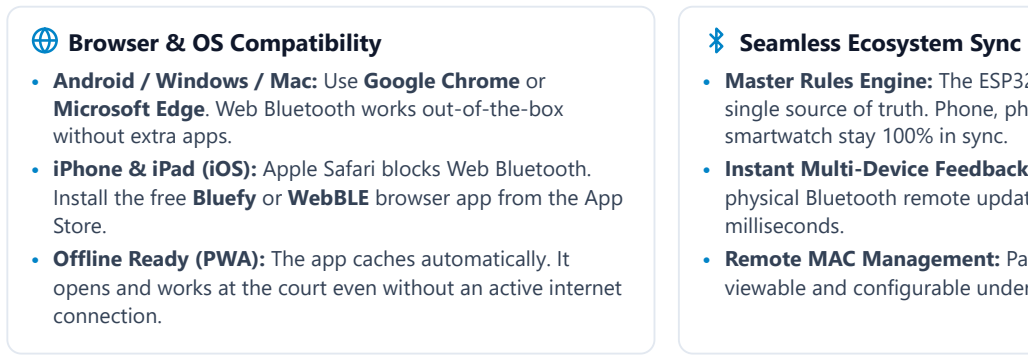
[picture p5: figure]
Browser & OS Compatibility; Seamless Ecosystem Sync; without extra apps.; Store.; connection.; smartwatch stay 100% in sync.; milliseconds.

ESP32-C3 SuperMini • Progressive Web App (PWA) • Web Bluetooth BLE | Full Match Control • RTC Sync • Custom Rules & Brightness

Android / Windows / Mac: Use Google Chrome or Microsoft Edge. Web Bluetooth works out-of-the-box

iPhone & iPad (iOS): Apple Safari blocks Web Bluetooth. Install the free Bluefy or WebBLE browser app from the App

Offline Ready (PWA): The app caches automatically. It opens and works at the court even without an active internet

Master Rules Engine: The ESP32 scoreboard serves as the single source of truth. Phone, physical clicker, and

Instant Multi-Device Feedback: A point clicked on the physical Bluetooth remote updates the web app and watch in

Remote MAC Management: Paired Xiaomi clicker MAC is viewable and configurable under the Info tab.

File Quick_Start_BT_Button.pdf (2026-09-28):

# Bluetooth Remote Clicker

ESP32 7-Segment Padel Scoreboard • Quick Start Reference Guide

XYLY01 / XIAOYI_RC

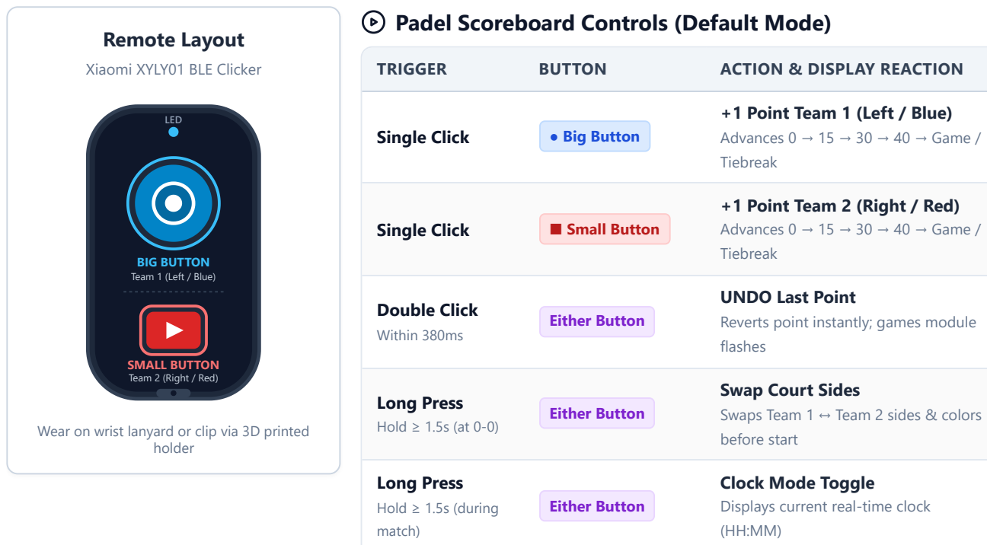
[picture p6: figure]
Remote Layout; Xiaomi XYLY01 BLE Clicker; LED; BIG BUTTON Team 1 (Left / Blue); SMALL BUTTON Team 2 (Right / Red); holder; TRIGGER; BUTTON; ACTION & DISPLAY REACTION; Single Click; ● Big Button; +1 Point Team 1 (Left / Blue) Advances 0 → 15 → 30 → 40 → Game / Tiebreak; ■ Small Button; +1 Point Team 2 (Right / Red) Advances 0 → 15 → 30 → 40 → Game / Tiebreak; Double Click Within 380ms; Either Button; UNDO Last Point Reverts point instantly; games module flashes; Long Press Hold ≥ 1.5s (at 0-0); Swap Court Sides Swaps Team 1 ↔ Team 2 sides & colors before start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
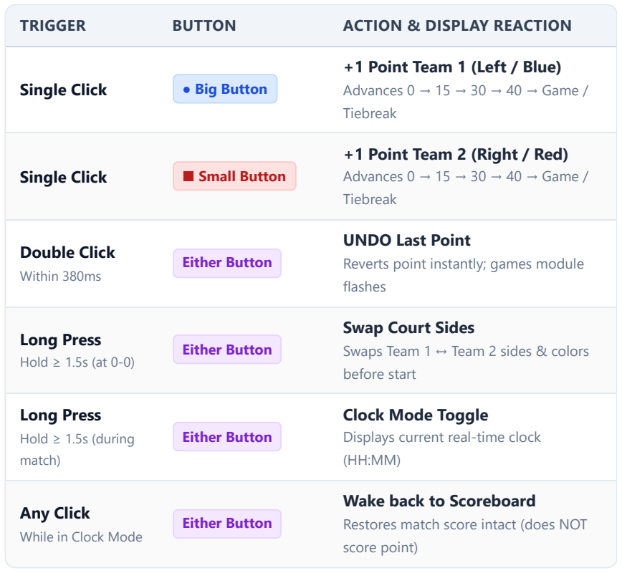
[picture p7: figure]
Any Click While in Clock Mode; Either Button; Wake back to Scoreboard Restores match score intact (does NOT score point)

Wear on wrist lanyard or clip via 3D printed

## Padel Scoreboard Controls (Default Mode)

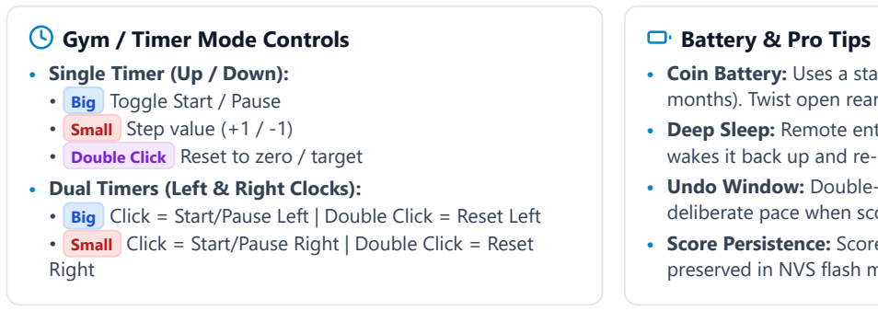
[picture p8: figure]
Gym / Timer Mode Controls; Battery & Pro Tips; Single Timer (Up / Down): • Big Toggle Start / Pause • Small Step value (+1 / -1) • Double Click Reset to zero / target; Dual Timers (Left & Right Clocks):; Right

ESP32-C3 SuperMini • WS2813 7-Segment Master Rules Engine | Auto-Pairing via BLE HID Profile (Service 0x1812)
- Big Click = Start/Pause Left | Double Click = Reset Left • Small Click = Start/Pause Right | Double Click = Reset | Coin Battery: Uses a standard CR1632 3V cell (lasts ~6–12 months). Twist open rear cap using a coin to replace. Deep Sleep: Remote enters sleep when unused. One click wakes it back up and re-links automatically. Undo Window: Double-click has a 380ms threshold. Keep deliberate pace when scoring consecutive points. Score Persistence: Scores and paired remote MAC are preserved in NVS flash memory across power cycles.

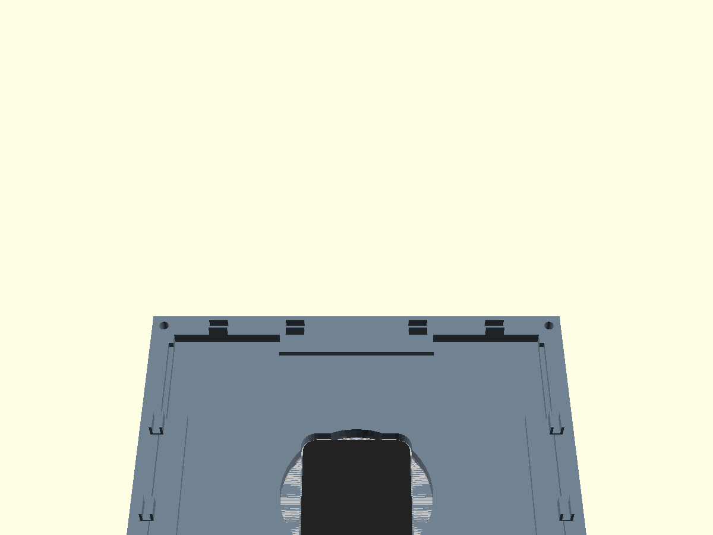
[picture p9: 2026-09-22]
scad/panel3_wpt_hardware_closeup.png

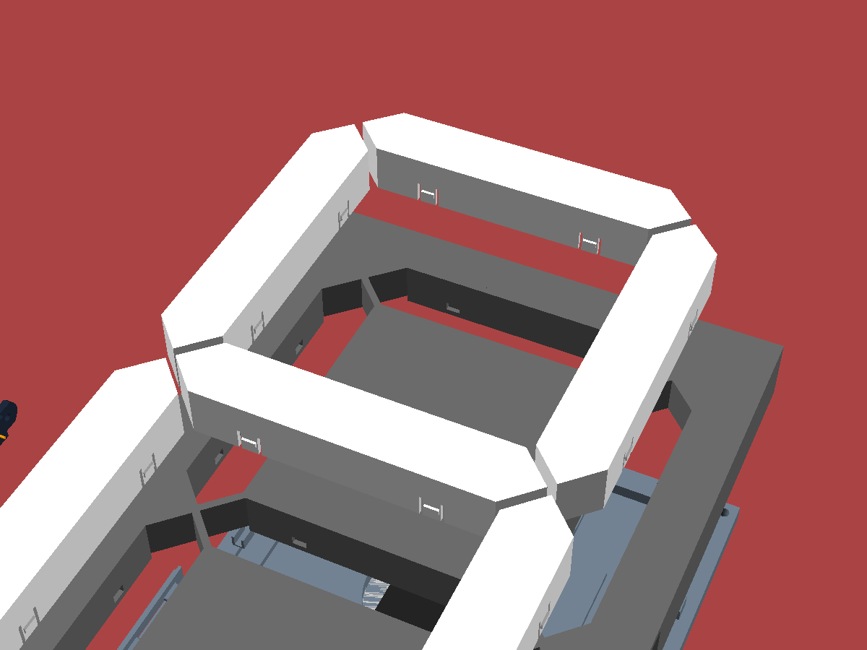
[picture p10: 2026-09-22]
scad/panel3_wpt_hardware_preview.png

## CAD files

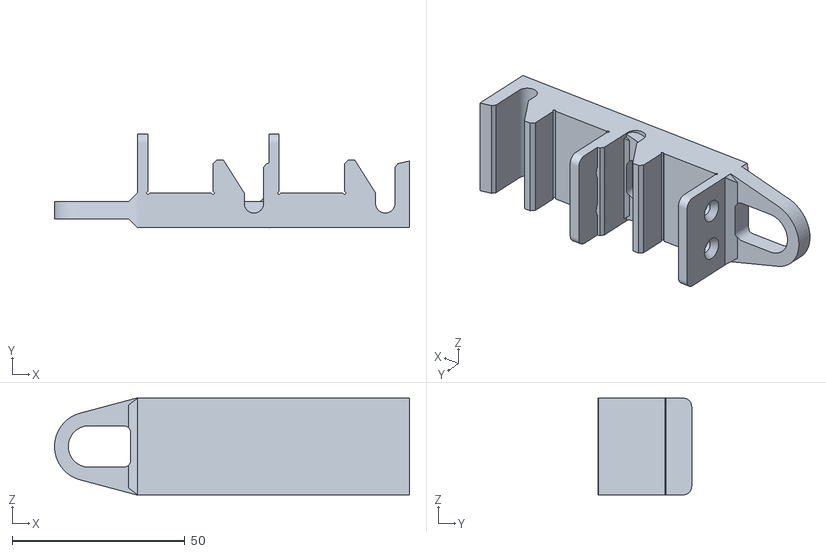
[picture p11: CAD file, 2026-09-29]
3d_models/panel_seam_u_hook_bracket_rear_eye_pair.stl
102.7 x 27.1 x 28.0

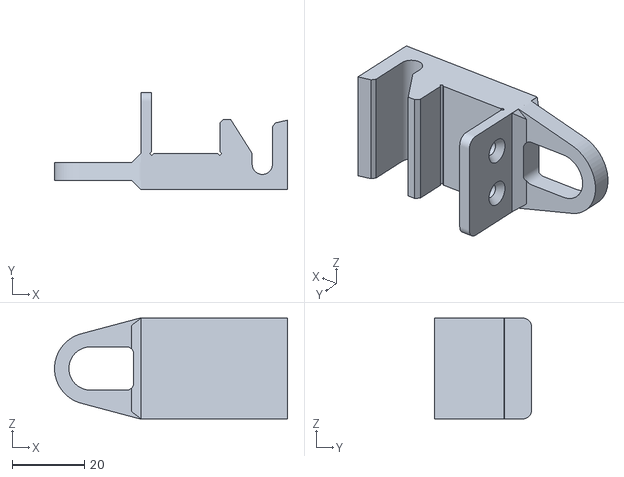
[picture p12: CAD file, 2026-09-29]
scad/panel_seam_u_hook_bracket_rear_eye.stl
64.7 x 27.1 x 28.0

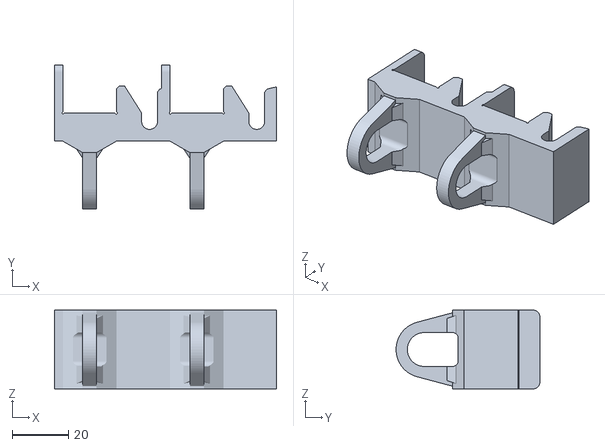
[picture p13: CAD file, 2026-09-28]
3d_models/panel_seam_u_hook_bracket_pair.stl
78.7 x 51.0 x 28.0

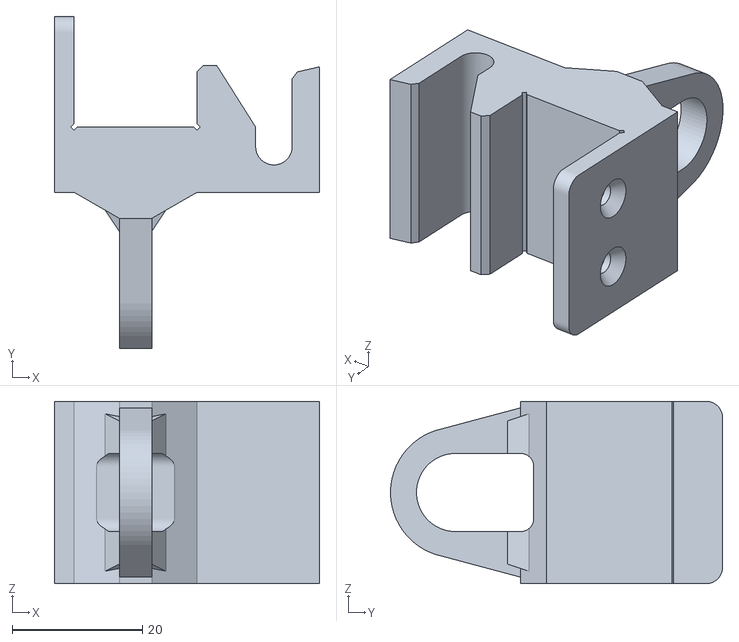
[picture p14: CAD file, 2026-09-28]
3d_models/panel_seam_u_hook_bracket.stl
40.7 x 51.0 x 28.0

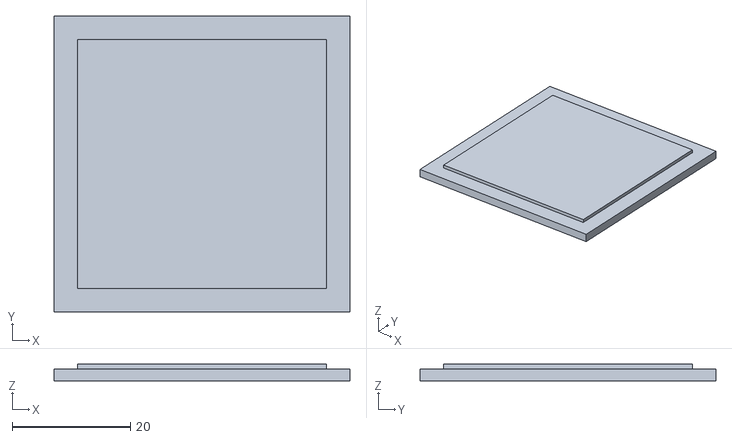
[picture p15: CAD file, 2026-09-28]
scad/qr.stl
50.0 x 50.0 x 2.80

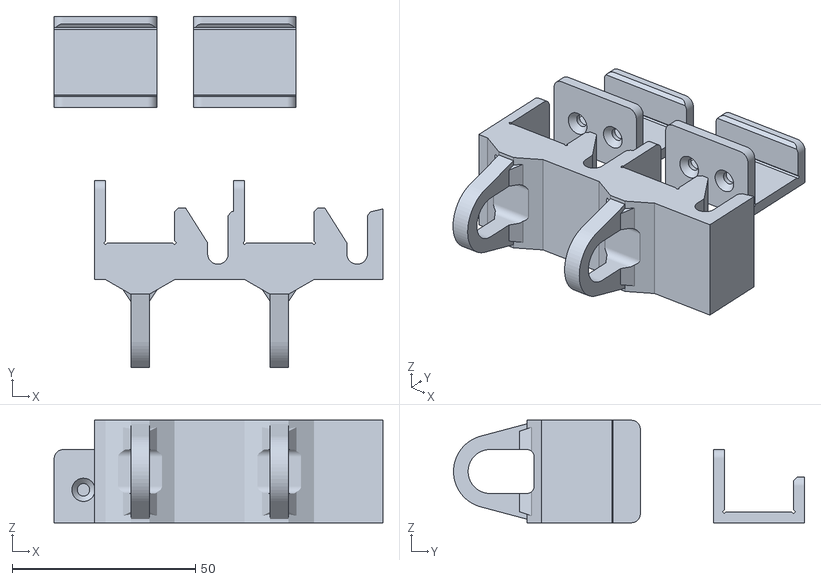
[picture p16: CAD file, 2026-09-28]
3d_models/panel_seam_u_bracket_set4_hook.stl
89.7 x 95.8 x 28.0

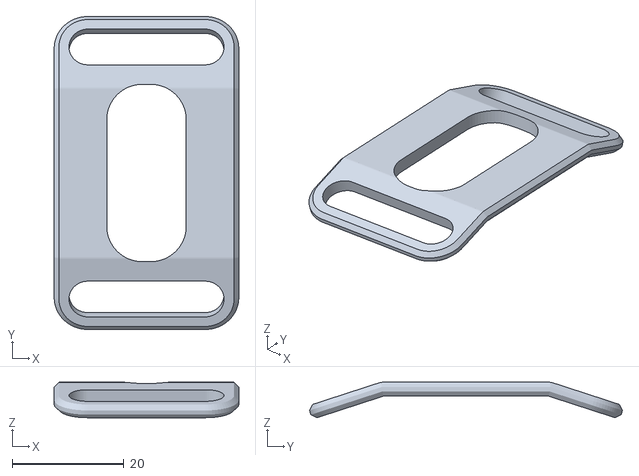
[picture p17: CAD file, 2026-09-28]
scad/remote_strap_holder.stl
33.0 x 55.9 x 6.35

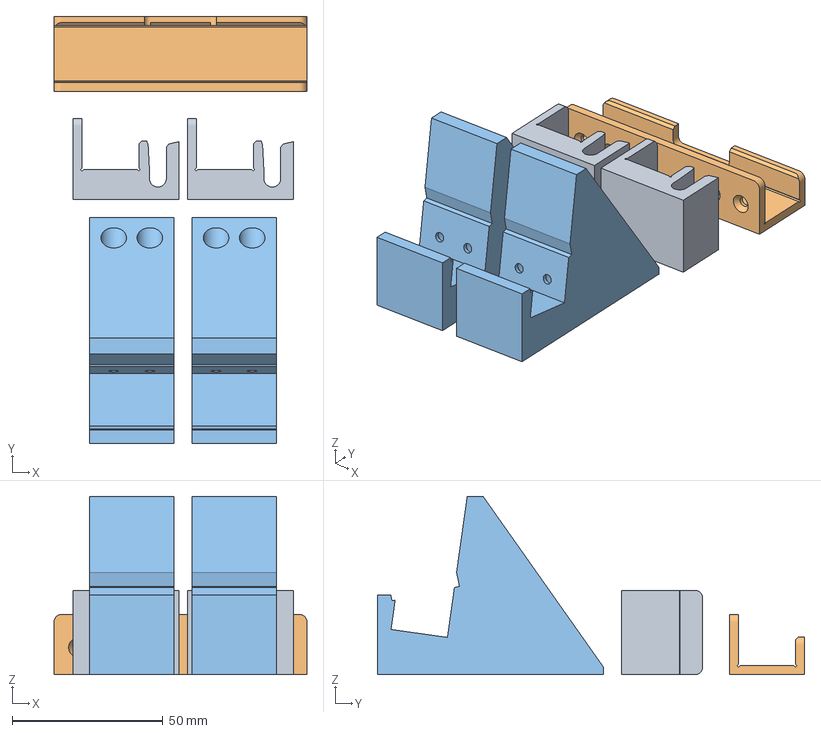
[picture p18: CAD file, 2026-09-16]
3d_models/panel_seam_u_bracket_set4.3mf
84.0 x 141.8 x 59.2 mm
panel_seam_u_hook_bracket_pair.stl
games_sets_u_bracket_cutout.stl
display_stand_40mm.stl

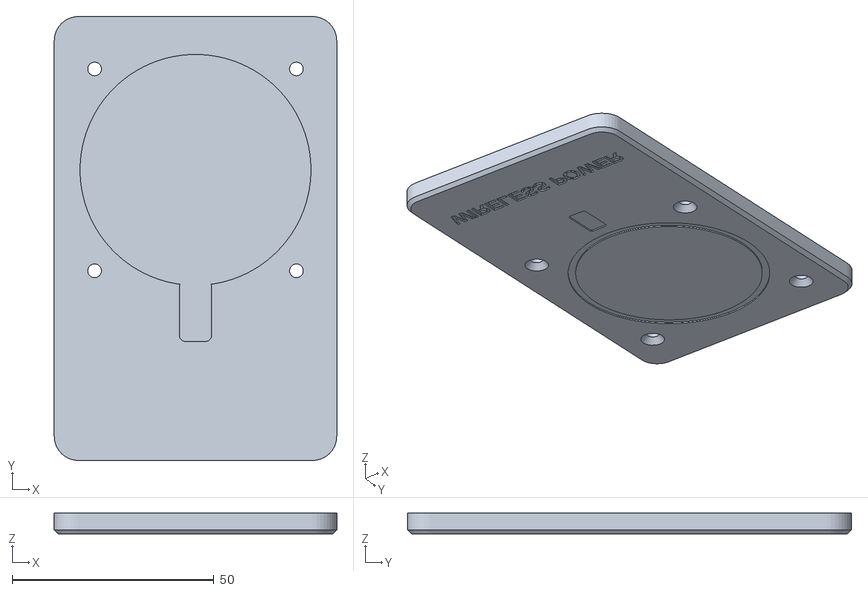
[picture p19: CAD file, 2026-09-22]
scad/vesa_wireless_power_addon.stl
70.0 x 110.0 x 5.20

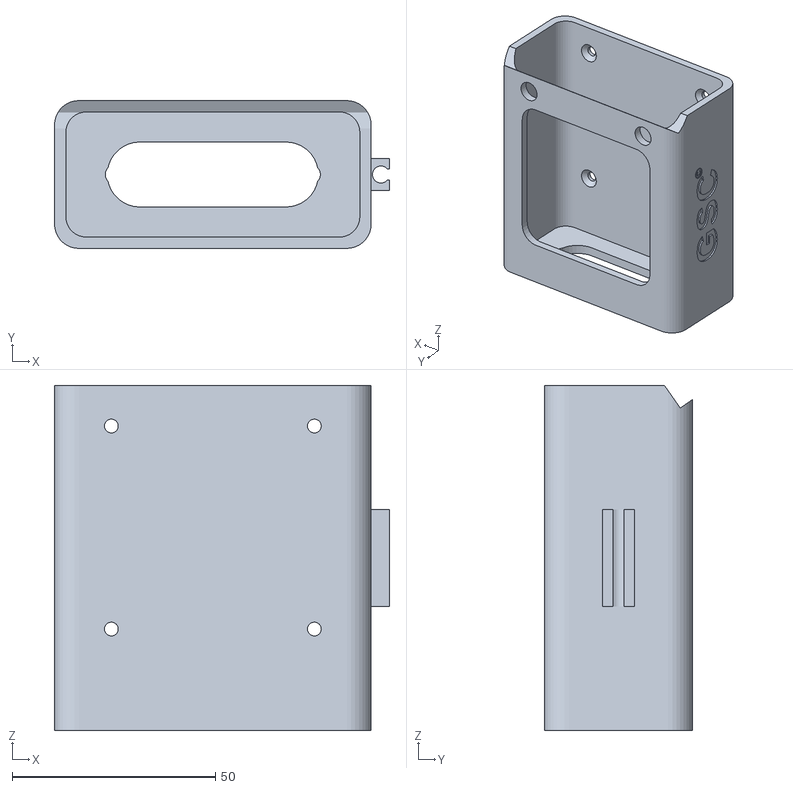
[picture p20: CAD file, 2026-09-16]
3d_models/padel_battery_holder.stl
82.5 x 36.4 x 85.0

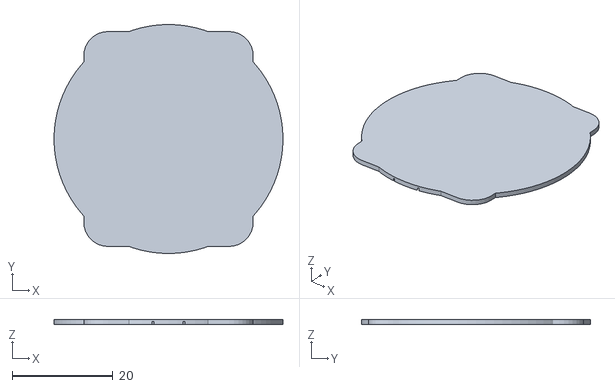
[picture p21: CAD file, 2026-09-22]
scad/panel3_wpt_lid.stl
45.4 x 45.4 x 1.00

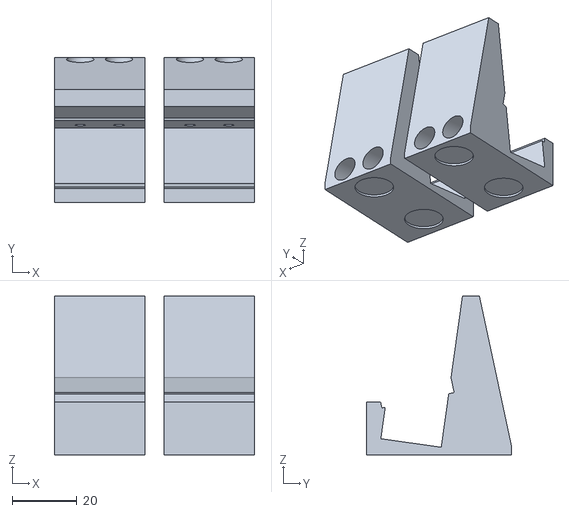
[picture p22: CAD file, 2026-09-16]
3d_models/display_stand_cradle_pair.stl
62.0 x 45.1 x 49.2

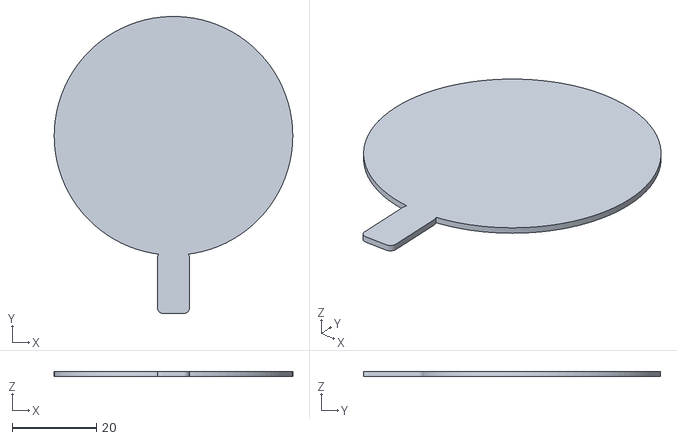
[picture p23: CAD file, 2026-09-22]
scad/vesa_wpt_cover.stl
56.8 x 70.7 x 1.20

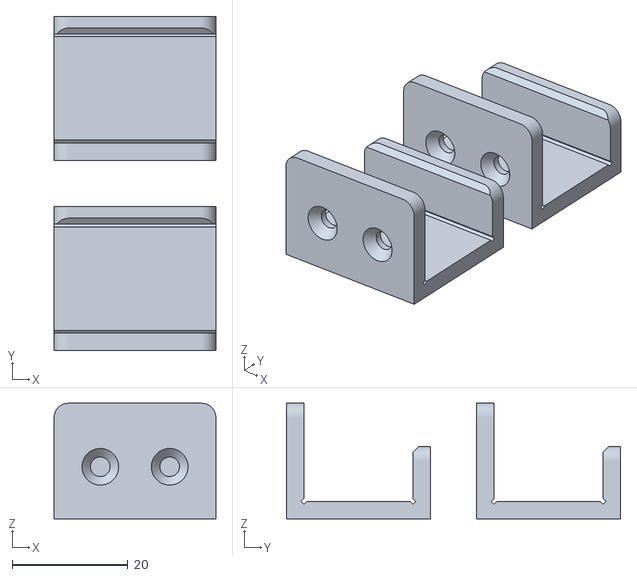
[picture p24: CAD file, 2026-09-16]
3d_models/panel_seam_u_bracket_pair.stl
28.0 x 57.8 x 20.0

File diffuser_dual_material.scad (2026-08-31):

// =========================================================================
// 7-Segment Dual-Material Diffuser (0.8 mm Total Thickness)
// Layer 1 (0.0 to 0.2 mm) = White Filament (100% surface diffusion)
// Layer 2 (0.2 to 0.8 mm) = Transparent / Clear Filament (Structural core)
// =========================================================================

// --- Configuration Parameters ---
pitch_x         = 92.0;   // Horizontal pitch between vertical columns
pitch_y_top     = 92.0;   // Pitch between middle & top horizontal segments
pitch_y_bot     = 92.0;   // Pitch between middle & bottom horizontal segments

total_seg_w     = 18.0;   // Segment width (18mm)
total_seg_l_x   = 104.0;  // Horizontal segment length (A, D, G)
total_seg_l_y_top = 104.0;// Top vertical segment length (B, F)
total_seg_l_y_bot = 117.0;// Bottom vertical segment length (C, E)

layer1_thick    = 0.2;    // First layer: 0.20 mm White
total_thick     = 0.8;    // Total thickness: 0.80 mm (0.6mm Transparent backing)

// --- Render Selection ---
render_part = 0; // 0: Dual-color assembly preview
                 // 1: White layer only (export STL)
                 // 2: Transparent layer only (export STL)
                 // 3: Single solid 0.8mm piece (export STL for slicer layer-pause)

// --- Segment Polygon Generator ---
module segment_shape(l, w, h) {
    linear_extrude(height = h)
    polygon([
        [-l/2, 0],
        [-l/2 + w/2, -w/2],
        [l/2 - w/2, -w/2],
        [l/2, 0],
        [l/2 - w/2, w/2],
        [-l/2 + w/2, w/2]
    ]);
}

// --- 7-Segment Layout Helpers ---
module layout_7segments(h) {
    // 1. Segment A (Top)
    translate([0, pitch_y_top, 0]) 
        segment_shape(total_seg_l_x, total_seg_w, h);

    // 2. Segment B (Top-Right)
    translate([pitch_x/2, pitch_y_top/2, 0]) rotate([0, 0, 90]) 
        segment_shape(total_seg_l_y_top, total_seg_w, h);

    // 3. Segment C (Bottom-Right)
    translate([pitch_x/2, -pitch_y_bot/2, 0]) rotate([0, 0, 90]) 
        segment_shape(total_seg_l_y_bot, total_seg_w, h);

    // 4. Segment D (Bottom)
    translate([0, -pitch_y_bot, 0]) 
        segment_shape(total_seg_l_x, total_seg_w, h);

    // 5. Segment E (Bottom-Left)
    translate([-pitch_x/2, -pitch_y_bot/2, 0]) rotate([0, 0, 90]) 
        segment_shape(total_seg_l_y_bot, total_seg_w, h);

    // 6. Segment F (Top-Left)
    translate([-pitch_x/2, pitch_y_top/2, 0]) rotate([0, 0, 90]) 
        segment_shape(total_seg_l_y_top, total_seg_w, h);

    // 7. Segment G (Middle)
    translate([0, 0, 0]) 
        segment_shape(total_seg_l_x, total_seg_w, h);
}

// --- White Layer (0.0 to 0.2 mm) ---
module diffuser_white() {
    color("White")
        layout_7segments(layer1_thick);
}

// --- Transparent Layer (0.2 to 0.8 mm) ---
module diffuser_transparent() {
    color("Cyan", 0.5) // Transparent cyan preview
        translate([0, 0, layer1_thick])
            layout_7segments(total_thick - layer1_thick);
}

// --- Assembly Rendering ---
if (render_part == 0) {
    diffuser_white();
    diffuser_transparent();
} else if (render_part == 1) {
    diffuser_white();
} else if (render_part == 2) {
    diffuser_transparent();
} else if (render_part == 3) {
    color("GhostWhite")
        layout_7segments(total_thick);
}

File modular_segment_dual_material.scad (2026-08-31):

// =========================================================================
// Modular 7-Segment Lightguide / Diffuser with Snaps (Dual Material)
// PRINT ORIENTATION: Flat front diffuser face on the print bed (Z = 0)
// - Layer 1 (White):        Z = 0.0 to 0.4 mm (2 solid layers of White @ 0.20mm)
// - Body (Transparent):     Z = 0.4 to 13.0 mm (0.4mm transparent core + 12.2mm hollow walls + snaps)
// ZERO OVERLAP: Layer 1 is strictly [0.0, 0.4], Layer 2 is strictly [0.4, 13.0]
// =========================================================================

/* [Parameters] */
diffuser_thick = 0.8;          // 0.8mm total diffuser face
layer1_white_thick = 0.4;      // 0.4mm white front layer (2 layers @ 0.20mm)
enable_segment_snaps = true;   // Snap teeth enabled
segment_clearance = 0.15;      // 0.15mm perimeter clearance

total_depth = 13.0;            // Total housing depth (13.0 mm)
tunnel_depth = total_depth - diffuser_thick; // Inner cavity depth (12.2 mm)

pitch_x = 92.0;
pitch_y_top = 92.0;
pitch_y_bot = 92.0;
strip_width = 12.0;
white_wall = 1.2;
front_wall = 2.0;

diffuser_w = strip_width + 2;               // 14.0 mm
total_seg_w = diffuser_w + white_wall * 2;  // 16.4 mm

total_seg_l_x = pitch_x - front_wall * 1.4142;      // 89.17 mm
total_seg_l_y_top = pitch_y_top - front_wall * 1.4142;
total_seg_l_y_bot = pitch_y_bot - front_wall * 1.4142;
diffuser_l_x = total_seg_l_x - white_wall * 2;      // 86.77 mm
diffuser_l_y_top = total_seg_l_y_top - white_wall * 2;
diffuser_l_y_bot = total_seg_l_y_bot - white_wall * 2;

// --- Shapes & Helpers ---
module segment_shape_2d(l, w) {
    polygon([
        [-l/2 + w/2, -w/2],
        [l/2 - w/2, -w/2],
        [l/2, 0],
        [l/2 - w/2, w/2],
        [-l/2 + w/2, w/2],
        [-l/2, 0]
    ]);
}

module segment_shape(l, w, h) {
    linear_extrude(height = h)
        segment_shape_2d(l, w);
}

// Snap teeth: positioned near the open top (at Z = total_depth - 3.0 = 10.0mm from bed)
module single_segment_snap_teeth_print_orient(l = total_seg_l_x, w = total_seg_w) {
    if (enable_segment_snaps) {
        tooth_w = 3.5;
        tooth_h = 2.2;
        tooth_reach = 0.45;
        z_pos = total_depth - 3.0; // 10.0mm above print bed
        
        for (side = [-1, 1]) {
            for (x_pos = [-22.0, 22.0]) {
                translate([x_pos, side * (w/2 - segment_clearance), z_pos]) {
                    rotate([side > 0 ? 0 : 180, 0, 0])
                        rotate([0, 90, 0])
                            linear_extrude(tooth_w, center=true)
                                polygon([
                                    [-tooth_h/2, -0.4],
                                    [-tooth_h/4, tooth_reach],
                                    [tooth_h/4, tooth_reach],
                                    [tooth_h/2, -0.4]
                                ]);
                }
            }
        }
    }
}

// Flex relief slits flanking snap teeth (cutting from top down)
module single_segment_flex_slits_print_orient(w = total_seg_w) {
    if (enable_segment_snaps) {
        slit_w = 0.8;
        slit_l = 3.5;
        slit_h = 5.5;
        z_center = total_depth - slit_h/2;
        
        for (side = [-1, 1]) {
            for (x_center = [-22.0, 22.0]) {
                for (dx = [-2.5, 2.5]) {
                    translate([x_center + dx, side * (w/2 - segment_clearance), z_center + 0.1])
                        cube([slit_w, slit_l, slit_h + 0.2], center=true);
                }
            }
        }
    }
}

// --- 1. Layer 1 (White Filament): Strictly Z = 0.0 to 0.40 mm ---
module single_segment_WHITE_layer1(l = total_seg_l_x, w = total_seg_w) {
    eff_w = w - segment_clearance * 2;
    eff_l = l - segment_clearance * 2;
    segment_shape(eff_l, eff_w, layer1_white_thick);
}

// --- 2. Body (Transparent Filament): Strictly Z = 0.40 to 13.00 mm ---
module single_segment_TRANSPARENT_body(l = total_seg_l_x, w = total_seg_w) {
    eff_w = w - segment_clearance * 2;
    eff_l = l - segment_clearance * 2;
    inner_w = diffuser_w;
    inner_l = l - white_wall * 2;
    
    // Starts strictly at Z = 0.40mm
    translate([0, 0, layer1_white_thick]) {
        difference() {
            union() {
                // Outer shell from Z = 0.4 to 13.0 (height = 12.6mm)
                segment_shape(eff_l, eff_w, total_depth - layer1_white_thick);
                
                // Snap teeth (shifted relative to Z=0.4)
                translate([0, 0, -layer1_white_thick])
                    single_segment_snap_teeth_print_orient(l, w);
            }
            
            // Hollow inner cavity: starts at Z = (diffuser_thick - layer1_white_thick = 0.4mm) above the transparent floor
            // Cuts all the way open through the top at Z = 13.0mm
            translate([0, 0, diffuser_thick - layer1_white_thick])
                segment_shape(inner_l, inner_w, total_depth - diffuser_thick + 1.0);
                
            // Flex slits
            translate([0, 0, -layer1_white_thick])
                single_segment_flex_slits_print_orient(w);
        }
    }
}

// --- 3. Full Solid Single Piece (Z = 0.0 to 13.0 mm) ---
module single_segment_SOLID(l = total_seg_l_x, w = total_seg_w) {
    eff_w = w - segment_clearance * 2;
    eff_l = l - segment_clearance * 2;
    inner_w = diffuser_w;
    inner_l = l - white_wall * 2;
    
    difference() {
        union() {
            segment_shape(eff_l, eff_w, total_depth);
            single_segment_snap_teeth_print_orient(l, w);
        }
        translate([0, 0, diffuser_thick])
            segment_shape(inner_l, inner_w, total_depth - diffuser_thick + 1.0);
        single_segment_flex_slits_print_orient(w);
    }
}

// --- 7-Segment Assembly Layouts ---
module layout_7segments_white() {
    translate([0, pitch_y_top, 0]) single_segment_WHITE_layer1(total_seg_l_x, total_seg_w);
    translate([pitch_x/2, pitch_y_top/2, 0]) rotate([0, 0, 90]) single_segment_WHITE_layer1(total_seg_l_y_top, total_seg_w);
    translate([pitch_x/2, -pitch_y_bot/2, 0]) rotate([0, 0, 90]) single_segment_WHITE_layer1(total_seg_l_y_bot, total_seg_w);
    translate([0, -pitch_y_bot, 0]) single_segment_WHITE_layer1(total_seg_l_x, total_seg_w);
    translate([-pitch_x/2, -pitch_y_bot/2, 0]) rotate([0, 0, 90]) single_segment_WHITE_layer1(total_seg_l_y_bot, total_seg_w);
    translate([-pitch_x/2, pitch_y_top/2, 0]) rotate([0, 0, 90]) single_segment_WHITE_layer1(total_seg_l_y_top, total_seg_w);
    translate([0, 0, 0]) single_segment_WHITE_layer1(total_seg_l_x, total_seg_w);
}

module layout_7segments_transp() {
    translate([0, pitch_y_top, 0]) single_segment_TRANSPARENT_body(total_seg_l_x, total_seg_w);
    translate([pitch_x/2, pitch_y_top/2, 0]) rotate([0, 0, 90]) single_segment_TRANSPARENT_body(total_seg_l_y_top, total_seg_w);
    translate([pitch_x/2, -pitch_y_bot/2, 0]) rotate([0, 0, 90]) single_segment_TRANSPARENT_body(total_seg_l_y_bot, total_seg_w);
    translate([0, -pitch_y_bot, 0]) single_segment_TRANSPARENT_body(total_seg_l_x, total_seg_w);
    translate([-pitch_x/2, -pitch_y_bot/2, 0]) rotate([0, 0, 90]) single_segment_TRANSPARENT_body(total_seg_l_y_bot, total_seg_w);
    translate([-pitch_x/2, pitch_y_top/2, 0]) rotate([0, 0, 90]) single_segment_TRANSPARENT_body(total_seg_l_y_top, total_seg_w);
    translate([0, 0, 0]) single_segment_TRANSPARENT_body(total_seg_l_x, total_seg_w);
}

module layout_7segments_solid() {
    translate([0, pitch_y_top, 0]) single_segment_SOLID(total_seg_l_x, total_seg_w);
    translate([pitch_x/2, pitch_y_top/2, 0]) rotate([0, 0, 90]) single_segment_SOLID(total_seg_l_y_top, total_seg_w);
    translate([pitch_x/2, -pitch_y_bot/2, 0]) rotate([0, 0, 90]) single_segment_SOLID(total_seg_l_y_bot, total_seg_w);
    translate([0, -pitch_y_bot, 0]) single_segment_SOLID(total_seg_l_x, total_seg_w);
    translate([-pitch_x/2, -pitch_y_bot/2, 0]) rotate([0, 0, 90]) single_segment_SOLID(total_seg_l_y_bot, total_seg_w);
    translate([-pitch_x/2, pitch_y_top/2, 0]) rotate([0, 0, 90]) single_segment_SOLID(total_seg_l_y_top, total_seg_w);
    translate([0, 0, 0]) single_segment_SOLID(total_seg_l_x, total_seg_w);
}

// --- Render Selection ---
render_target = "preview"; // ["preview", "single_white", "single_transp", "single_solid", "all_white", "all_transp", "all_solid"]

if (render_target == "preview") {
    color("White") single_segment_WHITE_layer1();
    color("Cyan", 0.6) single_segment_TRANSPARENT_body();
} else if (render_target == "single_white") {
    single_segment_WHITE_layer1();
} else if (render_target == "single_transp") {
    single_segment_TRANSPARENT_body();
} else if (render_target == "single_solid") {
    single_segment_SOLID();
} else if (render_target == "all_white") {
    layout_7segments_white();
} else if (render_target == "all_transp") {
    layout_7segments_transp();
} else if (render_target == "all_solid") {
    layout_7segments_solid();
}

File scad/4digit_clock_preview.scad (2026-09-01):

// 4-Digit Clock Preview Assembly (No Colon)
// Uses components from 7segment_v1

// Modular 7-Segment Display (Backplate & Frontplate Design for AMS)
// Configured for 93 mm parallel strip pitch, 105 mm total segment length with connector,
// 68 mm LED strip length, and 4.5 mm thick 90° corner connectors.

// --- Key Parameters ---

pitch = 83;             // Center-to-center distance between parallel LED strips (83 mm)
seg_length = 110;       // Total segment length including connectors on backplate (110 mm)
strip_length = 56;      // Active LED strip length (56 mm)
strip_width = 12;       // Width of LED strip (12 mm)
connector_thick = 4.0;  // Thickness / depth of the 90° corner connector (4.0 mm, 2mm below strip recess)
connector_len = (seg_length - strip_length) / 2; // 27 mm connector allowance per end
connector_width = 27;   // Width allowance for 90° solderless clip connector

tunnel_depth = 12;      // Depth of the light tunnel
diffuser_thick = 1.0;   // Thickness of the white top diffuser layer
white_wall = 1.2;       // Thickness of the white inner reflector walls
front_wall = 2.0;       // Black divider wall thickness between segment diffusers

backplate_floor = 1.5;  // Solid base floor under connector pockets
backplate_thick = connector_thick + backplate_floor; // 6.0 mm total backplate thickness
strip_recess_depth = 2.0; // Depth of LED strip recess

margin_x = 15;          // Extra bezel space on left and right sides
margin_y = 15;          // Extra bezel space on top and bottom sides

// --- Calculated Dimensions ---
diffuser_w = strip_width + 2;      // inner diffuser width
total_seg_w = diffuser_w + white_wall * 2; // outer white cup width

// Ensure a solid black wall of thickness 'front_wall' between the mitered segments
total_seg_l = pitch - front_wall * 1.4142; 
diffuser_l = total_seg_l - white_wall * 2;

digit_width = pitch + total_seg_w + margin_x * 2;      // 138.4 mm
digit_height = pitch * 2 + total_seg_w + margin_y * 2; // 231.4 mm
total_depth = tunnel_depth + diffuser_thick;           // 13 mm

// --- Shapes ---

// Pointy-end polygon for classic 7-segment display aesthetic (centered at origin)
module segment_shape(l, w, h) {
    translate([0, 0, -0.1])
    linear_extrude(height = h + 0.2)
    polygon([
        [-l/2 + w/2, -w/2],
        [l/2 - w/2, -w/2],
        [l/2, 0],
        [l/2 - w/2, w/2],
        [-l/2 + w/2, w/2],
        [-l/2, 0]
    ]);
}

// Layout helper for placing all 7 segments (A, B, C, D, E, F, G) on 93 mm pitch
module layout_7_segments() {
    // G - Middle (horizontal at y = 0)
    translate([0, 0, 0])
        children();
        
    // A - Top (horizontal at y = +pitch)
    translate([0, pitch, 0])
        children();
        
    // D - Bottom (horizontal at y = -pitch)
    translate([0, -pitch, 0])
        children();
        
    // F - Top Left (vertical at x = -pitch/2, y = +pitch/2)
    translate([-pitch/2, pitch/2, 0])
        rotate([0, 0, 90])
        children();
        
    // E - Bottom Left (vertical at x = -pitch/2, y = -pitch/2)
    translate([-pitch/2, -pitch/2, 0])
        rotate([0, 0, 90])
        children();
        
    // B - Top Right (vertical at x = +pitch/2, y = +pitch/2)
    translate([pitch/2, pitch/2, 0])
        rotate([0, 0, 90])
        children();
        
    // C - Bottom Right (vertical at x = +pitch/2, y = -pitch/2)
    translate([pitch/2, -pitch/2, 0])
        rotate([0, 0, 90])
        children();
}

// LED strip & connector channels on backplate
module led_strip_channel() {
    // Centered 68mm LED strip channel (depth = 2.0 mm)
    translate([-strip_length/2, -strip_width/2, -strip_recess_depth])
        cube([strip_length, strip_width, strip_recess_depth + 0.1]);
        
    // 18.5mm end connector channels (depth = 4.5 mm)
    translate([-seg_length/2 - 0.1, -connector_width/2, -connector_thick])
        cube([connector_len + 0.2, connector_width, connector_thick + 0.1]);
        
    translate([seg_length/2 - connector_len - 0.1, -connector_width/2, -connector_thick])
        cube([connector_len + 0.2, connector_width, connector_thick + 0.1]);
}

// --- Components ---

module frontplate_black(panel_id=4) {
    difference() {
        union() {
            // 1. Main frame (hollowed out from the back, leaving 2mm walls and 2mm front face)
            // Modified for v1 to extend the outer skirt down over the backplate
            difference() {
                translate([-digit_width/2, -digit_height/2, -backplate_thick]) 
                    cube([digit_width, digit_height, total_depth + backplate_thick]);
                translate([-digit_width/2 + 2, -digit_height/2 + 2, -backplate_thick - 1]) 
                    cube([digit_width - 4, digit_height - 4, total_depth + backplate_thick - 1]);
            }
            
            // 2. Black walls around the segments (to prevent light bleed)
            layout_7_segments()
                segment_shape(total_seg_l + 4, total_seg_w + 4, total_depth);
                
            // 3. Screw posts for backplate
            translate([digit_width/2 - 6, digit_height/2 - 6, 0]) cylinder(h=total_depth, r=4, $fn=20);
            translate([-digit_width/2 + 6, digit_height/2 - 6, 0]) cylinder(h=total_depth, r=4, $fn=20);
            translate([digit_width/2 - 6, -digit_height/2 + 6, 0]) cylinder(h=total_depth, r=4, $fn=20);
            translate([-digit_width/2 + 6, -digit_height/2 + 6, 0]) cylinder(h=total_depth, r=4, $fn=20);
            
            // 4. Mounting bosses for side screws
            for (y = [digit_height/3, -digit_height/3]) {
                // Right side gets mounting bosses (unless it's panel 4, the last panel)
                if (panel_id < 4) {
                    translate([digit_width/2 - 2, y, tunnel_depth/2 + 0.5]) cube([4, 15, tunnel_depth + 1], center=true);
                }
                // Left side gets mounting bosses only if it's panel 2 or higher (to attach to the previous panel)
                if (panel_id > 1) {
                    translate([-digit_width/2 + 2, y, tunnel_depth/2 + 0.5]) cube([4, 15, tunnel_depth + 1], center=true);
                }
            }
            
            // Inter-panel alignment protrusion (Right side, robust 12x12 male flange sticking out 2mm)
            if (panel_id < 4) {
                translate([digit_width/2, 0, tunnel_depth/2]) 
                    cube([4, 12.0, 12.0], center=true);
            }
        }
        
        // NOW cut out the actual white segment spaces
        layout_7_segments()
            translate([0, 0, -1]) // Ensure clean cut through the front face
            segment_shape(total_seg_l, total_seg_w, total_depth + 2);
            
        // Screw holes for backplate to mount (sized for standard M3 heat-set inserts, 4.2mm diameter)
        // Penetrates slightly into the 2mm front roof (Z=total_depth - 1.5) to avoid exact flush non-manifold faces
        translate([digit_width/2 - 6, digit_height/2 - 6, -1]) cylinder(h=total_depth - 0.5, r=2.1, $fn=20);
        translate([-digit_width/2 + 6, digit_height/2 - 6, -1]) cylinder(h=total_depth - 0.5, r=2.1, $fn=20);
        translate([digit_width/2 - 6, -digit_height/2 + 6, -1]) cylinder(h=total_depth - 0.5, r=2.1, $fn=20);
        translate([-digit_width/2 + 6, -digit_height/2 + 6, -1]) cylinder(h=total_depth - 0.5, r=2.1, $fn=20);
        
        // Side mounting holes
        for (y = [digit_height/3, -digit_height/3]) {
            // Right side gets clearance holes for the screws (3.2mm) unless it's panel 4
            if (panel_id < 4) {
                translate([digit_width/2, y, tunnel_depth/2]) rotate([0, 90, 0]) cylinder(h=20, r=1.6, center=true, $fn=20);
            }
            
            if (panel_id > 1) {
                // Left side gets holes for heat-set inserts (4.2mm) to receive the screws from the previous panel
                translate([-digit_width/2, y, tunnel_depth/2]) rotate([0, 90, 0]) cylinder(h=20, r=2.1, center=true, $fn=20);
            }
        }
        
        if (panel_id == 1) {
            // USB-C Power Connector Cutout (Left side, centered)
            // Designed for the snap-in panel mount Type-C connector (approx 9.5mm x 5.0mm hole)
            translate([-digit_width/2, 0, tunnel_depth/2]) 
                cube([10, 9.5, 5.0], center=true);
        }
        
        // Inter-panel wire pass-through hole (Right side, outgoing wires to next digit)
        // This cuts a 6x6 hole through both the wall and the male alignment flange (leaving robust 3mm walls)
        if (panel_id < 4) {
            translate([digit_width/2, 0, tunnel_depth/2]) 
                cube([10, 6.0, 6.0], center=true);
        }
        
        // Inter-panel wire pass-through & alignment receiver (Left side, incoming wires)
        // This is a 12.5x12.5 female hole that perfectly receives the 12x12 male flange from the previous panel!
        if (panel_id > 1) {
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

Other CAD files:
scad/panel3_backplate_wpt.stl
3d_models/display_stand_40mm.stl
scad/7segment_lightguide.scad
3d_models/7segment_pogo back2.stl
3d_models/7segment_pogo back3.stl
3d_models/7segment_pogo back4.stl
3d_models/7segment_pogo.stl
3d_models/7segment_pogo_FP_2and3.stl
3d_models/7segment_pogo_FP_4.stl
3d_models/digit_set_7segments_white.stl
3d_models/display_stand.stl
3d_models/display_stand_cradle_single.stl
3d_models/games_sets_pogo_snap_individual_dots.stl
3d_models/games_sets_pogo_snap_individual_dots_FPB.stl
3d_models/games_sets_pogo_snap_individual_dots_back.stl
3d_models/games_sets_pogo_snap_individual_dots_txt.stl
3d_models/games_sets_u_bracket.stl
3d_models/games_sets_u_bracket_pair.stl
3d_models/padel_hook.stl
3d_models/panel_seam_u_bracket.stl
3d_models/panel_seam_u_bracket_set4.stl
3d_models/panel_thumbscrew.stl
3d_models/rear_corner_foot.stl
3d_models/rear_corner_foot_set4.stl
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

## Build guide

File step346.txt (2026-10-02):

I found the exact cause in the scoreboard's live connection logs!

### What Actually Happened:

When your scoreboard booted up and showed the green **`CONN`**, **it did not connect to the ring — it connected to your old Xiaomi remote (`XiaoYi_RC`)!**

Here is the exact line from the board's serial log:
```text
[SCAN] 04:e6:76:b2:8a:b6 | RSSI: -68 | 'XiaoYi_RC' | Services: [0x1812 ... ]
[SCAN] ★ RECOGNIZED PAIRED REMOTE (04:e6:76:b2:8a:b6)! Stopping scan to connect...
[BLE] Connecting to 04:e6:76:b2:8a:b6...
[BLE] Successfully connected to remote!
```

Because the old Xiaomi remote is powered on nearby, the scoreboard recognized its saved MAC address (`04:e6:76:b2:8a:b6`), immediately re-connected to it, and **stopped scanning**.

When you saw **`CONN`** on the scoreboard and pressed the buttons on the ring, the scoreboard was actively listening to the old Xiaomi remote, not the ring.

---

### To Connect to the Ring:

1. **Remove the battery or turn off the old Xiaomi remote** (or move it far away).
2. If you want, I can also clear the stored `04:e6:76:b2:8a:b6` pairing memory from the scoreboard right now so it never auto-connects to the old remote again.
3. Turn on the **WXLJ-02 ring** (ensure its LED is flashing).
4. Restart the scoreboard.

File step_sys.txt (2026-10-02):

The following is a <SYSTEM_MESSAGE> not actually sent by the user. It is provided by the system as important information to pay attention to.

<SYSTEM_MESSAGE>
[Message] timestamp=2026-10-02T12:54:01Z sender=675b21b6-b2c7-41c6-a630-370dd790e4d8/task-349 priority=MESSAGE_PRIORITY_HIGH content=Task id "675b21b6-b2c7-41c6-a630-370dd790e4d8/task-349" finished with result:

				The command exited with code 0.
				Output:
				<truncated 275 lines>
[SCAN] 4c:20:2d:6c:9c:48 | RSSI: -66 | 'Galaxy Watch5 Pro (QP7D)' | Services: [] | App: 0x00C0
[SCAN] 70:0f:8a:77:4c:e9 | RSSI: -57 | 'GEERTS_PC' | Services: [0x180a 3e1d50cd-7e3e-427d-8e1c-b78aa87fe624 ] | App: 0x0000
[SCAN] 41:d7:39:12:1f:d9 | RSSI: -77 | 'TY' | Services: [0xa201 ] | App: 0x0000
[SCAN] 1a:53:ed:43:8f:7f | RSSI: -57 | '' | Services: [] | App: 0x0000
[SCAN] 5f:19:15:5f:c2:0b | RSSI: -67 | 'Galaxy Watch5 Pro (QP7D)' | Services: [] | App: 0x00C0
[SCAN] 41:43:73:45:c7:87 | RSSI: -55 | '' | Services: [] | App: 0x0000
[SCAN] 47:c7:c7:bd:2c:78 | RSSI: -91 | '' | Services: [0xfe9f ] | App: 0x0000
[SCAN] 61:19:e6:3a:d2:cd | RSSI: -67 | 'Galaxy Watch5 Pro (QP7D)' | Services: [] | App: 0x00C0
[SCAN] 6f:6f:6f:f7:4f:7e | RSSI: -83 | '' | Services: [0xfe9f ] | App: 0x0000
[SCAN] 6d:c8:a1:ab:ce:1c | RSSI: -77 | 'Galaxy Watch5 Pro (QP7D)' | Services: [] | App: 0x00C0
[SCAN] 4c:20:2d:6c:9c:48 | RSSI: -77 | 'Galaxy Watch5 Pro (QP7D)' | Services: [] | App: 0x00C0
[SCAN] 48:cd:de:a6:66:1a | RSSI: -77 | 'Galaxy Watch5 Pro (QP7D)' | Services: [] | App: 0x00C0
[SCAN] 41:d7:39:12:1f:d9 | RSSI: -81 | 'TY' | Services: [0xa201 ] | App: 0x0000
[SCAN] 1a:53:ed:43:8f:7f | RSSI: -64 | '' | Services: [] | App: 0x0000
[SCAN] 6c:37:ba:a9:77:1f | RSSI: -90 | 'NestMini1602' | Services: [0xfea0 ] | App: 0x0000
[SCAN] fd:f1:f6:9e:78:b7 | RSSI: -81 | 'N00EW' | Services: [0xfeaf ] | App: 0x0000
[SCAN] 70:0f:8a:77:4c:e9 | RSSI: -67 | 'GEERTS_PC' | Services: [0x180a 3e1d50cd-7e3e-427d-8e1c-b78aa87fe624 ] | App: 0x0000
[SCAN] 41:d7:39:12:1f:d9 | RSSI: -78 | 'TY' | Services: [0xa201 ] | App: 0x0000
[S
<truncated 4640 bytes>
 0x0000
[SCAN] 70:0f:8a:77:4c:e9 | RSSI: -66 | 'GEERTS_PC' | Services: [0x180a 3e1d50cd-7e3e-427d-8e1c-b78aa87fe624 ] | App: 0x0000
[SCAN] 6b:22:43:79:73:b2 | RSSI: -67 | 'Galaxy Watch5 Pro (QP7D)' | Services: [] | App: 0x00C0
[SCAN] 65:49:e8:a6:8f:12 | RSSI: -66 | 'Galaxy Watch5 Pro (QP7D)' | Services: [] | App: 0x00C0
[SCAN] 6d:c8:a1:ab:ce:1c | RSSI: -67 | 'Galaxy Watch5 Pro (QP7D)' | Services: [] | App: 0x00C0
[SCAN] 6f:6f:6f:f7:4f:7e | RSSI: -82 | '' | Services: [0xfe9f ] | App: 0x0000
[SCAN] 5f:a5:c6:ce:4b:28 | RSSI: -68 | 'Galaxy Watch5 Pro (QP7D)' | Services: [] | App: 0x00C0
[SCAN] 48:cd:de:a6:66:1a | RSSI: -68 | 'Galaxy Watch5 Pro (QP7D)' | Services: [] | App: 0x00C0
[SCAN] 5f:19:15:5f:c2:0b | RSSI: -77 | 'Galaxy Watch5 Pro (QP7D)' | Services: [] | App: 0x00C0
[SCAN] 3c:1a:cc:ba:a8:ce | RSSI: -73 | 'MST_VNSE3_a8ce' | Services: [] | App: 0x0000
[SCAN] 41:d7:39:12:1f:d9 | RSSI: -82 | 'TY' | Services: [0xa201 ] | App: 0x0000
[SCAN] 61:19:e6:3a:d2:cd | RSSI: -77 | 'Galaxy Watch5 Pro (QP7D)' | Services: [] | App: 0x00C0
[SCAN] 1a:53:ed:43:8f:7f | RSSI: -64 | '' | Services: [] | App: 0x0000
[SCAN] 6d:74:76:64:43:71 | RSSI: -67 | 'Galaxy Watch5 Pro (QP7D)' | Services: [] | App: 0x00C0
[SCAN] 6b:22:43:79:73:b2 | RSSI: -67 | 'Galaxy Watch5 Pro (QP7D)' | Services: [] | App: 0x00C0
[SCAN] 70:0f:8a:77:4c:e9 | RSSI: -65 | 'GEERTS_PC' | Services: [0x180a 3e1d50cd-7e3e-427d-8e1c-b78aa87fe624 ] | App: 0x0000
[SCAN] 41:d7:39:12:1f:d9 | RSSI: -78 | 'TY' | Services: [0xa201 ] | App: 0x0000
[SCAN] 65:49:e8:a6:8f:12 | RSSI: -67 | 'Galaxy Watch5 Pro (QP7D)' | Services: [] | App: 0x00C0
[SCAN] 47:c7:c7:bd:2c:78 | RSSI: -96 | '' | Services: [0xfe9f ] | App: 0x0000
[SCAN] 4c:20:2d:6c:9c:48 | RSSI: -66 | 'Galaxy Watch5 Pro (QP7D)' | Services: [] | App: 0x00C0
[SCAN] 6f:6f:6f:f7:4f:7e | RSSI: -86 | '' | Services: [0xfe9f ] | App: 0x0000
Reset triggered. Listening for 10 seconds...

Log: file:///C:/Users/geert/.gemini/antigravity-ide/brain/675b21b6-b2c7-41c6-a630-370dd790e4d8/.system_generated/tasks/task-349.log
</SYSTEM_MESSAGE>

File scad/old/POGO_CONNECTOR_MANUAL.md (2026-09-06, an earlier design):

# Magnetic Pogo Pin Connector — Outside Mount Manual

This manual documents the **outside-mount installation** of the **5-pin magnetic pogo pin connector** into the modular 7-segment display and colon spacer housing.

---

## 1. Key Dimensions & Specifications

```
                       23.5 mm (Full Length across Ears)
◄─────────────────────────────────────────────────────────────────►
               20.0 mm (Center-to-Center Hole Pitch)
      ◄─────────────────────────────────────────────►
                     17.5 mm (Plug Body)
             ◄───────────────────────────────►
      ┌───────╭─────────────────────────────╮───────┐  ▲
      │  (O)  │  (N)   •   •   •   •   •  (S)│  (O)  │  │ 4.0 mm
      └───────╰─────────────────────────────╯───────┘  ▼
       Ear 1        Stadium Rounded Plug       Ear 2
      (Ø1.8mm)            (r = 2.0 mm)        (Ø1.8mm)
```

| Parameter | Physical Part | 3D CAD Pocket Dimension | Note |
| :--- | :--- | :--- | :--- |
| **Total Length across Ears** | `23.5 mm` | — | Ears sit flat on outside wall |
| **Hole Pitch (Center-to-Center)** | `20.0 mm` | `20.0 mm` | Exact hole alignment |
| **Central Body Width** | `17.5 mm` | `18.0 mm` | Stadium opening (+0.5 mm) |
| **Body Height / Thickness** | `4.0 mm` | `4.4 mm` | Stadium opening (+0.4 mm) |
| **Body Corner Radius** | `2.0 mm` | `2.2 mm` | Semi-circular rounded ends |
| **Rear Body Depth (behind ears)** | `2.0 mm` | `2.0 mm` | Inserts into 2.0mm wall |
| **Mounting Ear Thickness** | `1.0 mm` | — | Protrudes only 1.0 mm on outside |
| **Screw Size** | **M2 × 5 mm** (or **M2 × 6 mm**) | Pilot hole: `1.8 mm` | Screws into 6mm deep internal boss |

---

# Magnetic Pogo Pin Connector — Backplate-Mounted Manual

This manual documents the **backplate-integrated, outside-mount installation** of the **5-pin magnetic pogo pin connector** into the modular 7-segment display and colon spacer housing.

---

## 1. Backplate-Mounted Architecture

To ensure **all electrical wiring, soldering, and harness routing are 100% self-contained on the backplate**, the connectors (both USB-C and Magnetic Pogo Pins) are physically part of the **Backplate**:

1. **Backplate Connector Towers:** Monolithic vertical towers rise from the backplate on the left and right walls to house the pogo connectors and USB-C port.
2. **Wire-Free Frontplate:** The black frontplate acts purely as an optical hood and light diffuser bezel with matching stepped U-notches. It can be mounted and unmounted at any time with **zero attached wires**.
3. **Stepped Lap-Joint (Zero Light Bleed):** A 1.0 mm stepped labyrinth overlap between the backplate tower and frontplate U-notch guarantees complete light isolation and a flush exterior seam.

```
                        FRONTPLATE (Optical Hood)
                 (Slidably mounts over backplate along -Z)
                 ┌──────────────────────────────────────┐
                 │     [Stepped 1mm Rebate U-Notch]     │
                 └───╭──────────────────────────────╮───┘
                     │       1.0mm Step Lap         │
                     ▼                              ▼
                     
                     ▲                              ▲
                     │       1.0mm Step Lip         │
                 ┌───╰──────────────────────────────╯───┐
                 │       [Backplate Connector Tower]    │
                 │       • 23.9 x 4.4mm Stadium Pocket  │
                 │       • 2x M2 x 5mm Screw Bosses     │
                 │       • Sense Resistor Pocket        │
                 │                                      │
                 │              BACKPLATE               │
                 │       • 100% Wiring & Electronics    │
                 └──────────────────────────────────────┘
```

---

## 2. Key Dimensions & Specifications

```
                       23.5 mm (Full Length across Ears)
◄─────────────────────────────────────────────────────────────────►
               20.0 mm (Center-to-Center Hole Pitch)
      ◄─────────────────────────────────────────────►
                     17.5 mm (Plug Body)
             ◄───────────────────────────────►
      ┌───────╭─────────────────────────────╮───────┐  ▲
      │  (O)  │  (N)   •   •   •   •   •  (S)│  (O)  │  │ 4.0 mm
      └───────╰─────────────────────────────╯───────┘  ▼
       Ear 1        Stadium Rounded Plug       Ear 2
      (Ø1.8mm)            (r = 2.0 mm)        (Ø1.8mm)
```

| Parameter | Physical Part | 3D CAD Pocket Dimension | Note |
| :--- | :--- | :--- | :--- |
| **Total Length across Ears** | `23.5 mm` | `23.9 mm` | Ears sit flush in 3.0mm recessed pocket |
| **Hole Pitch (Center-to-Center)** | `20.0 mm` | `20.0 mm` | Exact hole alignment |
| **Central Body Width** | `17.5 mm` | `18.0 mm` | Stadium opening (+0.5 mm clearance) |
| **Body Height / Thickness** | `4.0 mm` | `4.4 mm` | Stadium opening (+0.4 mm clearance) |
| **Body Corner Radius** | `2.0 mm` | `2.2 mm` | Semi-circular rounded ends |
| **Screw Boss Depth** | — | `3.0 mm` | Recessed seating face from outer wall |
| **Screw Size** | **M2 × 5 mm** (or **M2 × 6 mm**) | Pilot hole: `1.8 mm` | Screws into 6mm deep internal boss |
| **Tower Width along Y** | — | `32.0 mm` | Centered at Y = 0 on backplate |
| **Stepped Lap Joint** | — | `1.0 mm` step | Labyrinth light trap against frontplate |

---

## 3. Mechanical Assembly Flow

```
[Step 1: Bench Assembly on Backplate]
    1. Install LED strips into the backplate channels.
    2. Snap ESP32 SuperMini into its backplate cradle (Panel 1).
    3. Install Pogo pin connectors into the backplate towers from outside.
    4. Fasten with 2x M2 x 5mm screws into the 1.8mm pilot holes.
    5. Solder wire harness and sense resistor directly on the backplate.
    6. Route all wires into the backplate floor cable retention clips.
    7. Fully test all electronics on the bench!

[Step 2: Install Frontplate]
    1. Slide the frontplate straight down over the backplate.
    2. The frontplate stepped U-notches smoothly wrap over the backplate connector towers.
    3. Secure with 4x M3 countersunk screws into the frontplate corner inserts.
    
    -> Zero wires are attached to the frontplate, allowing unlimited removal without risk!
```

---

## 4. Electrical Pinout & Wiring

```
        Pin 1        Pin 2        Pin 3        Pin 4        Pin 5
       [ +5V ]      [ GND ]      [ DATA ]     [ SENSE ]    [ RESV ]
     (Red Wire)  (Black Wire)  (Green Wire)  (Blue Wire)   (Optional)
```

```
Panel 1 (Left)                    Magnetic Seam                  Panel 2 (Right)
┌────────────────┐             ┌─────────────────┐             ┌────────────────┐
│ +5V Power      ├────────────►│ Pin 1: +5V      ├────────────►│ +5V Power      │
│ GND            ├────────────►│ Pin 2: GND      ├────────────►│ GND            │
│ LED Data Out   ├────────────►│ Pin 3: Data     ├────────────►│ LED Data In    │
│ Auto-Sense/ID  ├────────────►│ Pin 4: Sense    ├────────────►│ Auto-Sense/ID  │
└────────────────┘             └─────────────────┘             └────────────────┘
```

---

## 5. Quick Test Print Coupons

- **Test Coupon SCAD:** [`test_coupons_backplate_connectors.scad`](file:///c:/Users/geert/Documents/Github/7segment/scad/test_coupons_backplate_connectors.scad)
- **Included Tests:**
  - `backplate_pogo_tower`: Isolated backplate connector tower for testing pogo connector fit and screw bite.
  - `frontplate_stepped_notch`: Isolated frontplate cap for testing the stepped lap joint.
  - `both_side_by_side`: Rapid test print (~15 minutes on Bambu Lab) to verify tolerances, slide-in smoothness, and light-tight seal.

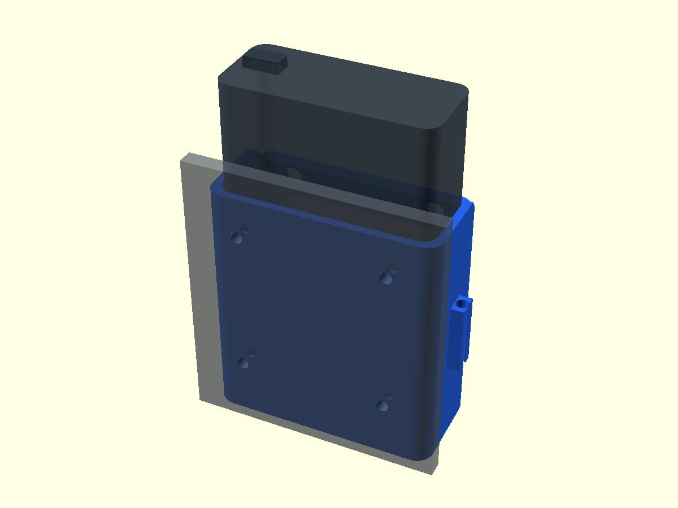
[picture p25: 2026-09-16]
Images/padel_battery_holder_vesa_assembly.png

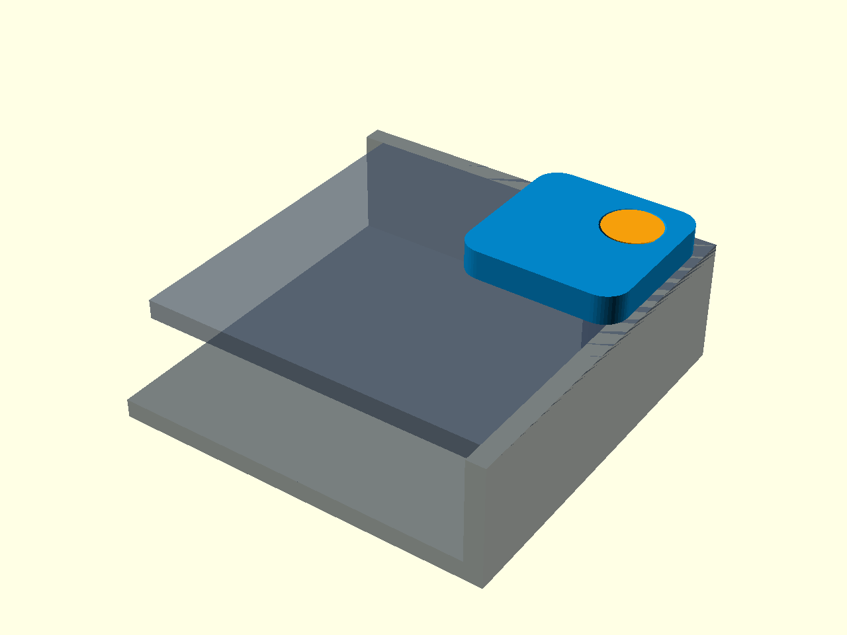
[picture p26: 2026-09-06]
Images/rear_corner_foot_assembly.png

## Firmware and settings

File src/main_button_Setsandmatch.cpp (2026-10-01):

// ==============================================================================
// ESP32 Padel Scoreboard - Xiaomi / YI Bluetooth Remote (XYLY01)
// Version: Sets & Match Edition (with Games & Sets Indicator Module)
//
// Remote Specifications:
//   Model: Xiaomi / YI Action Camera Remote (XYLY01, advertised as "XiaoYi_RC")
//   Protocol: BLE HID Report Characteristic (0x2A4D under Service 0x1812)
//   Big Button (Top / Shutter, 0x40): Point for Team 1 (Left / Blue)
//   Small Button (Bottom / Mode, 0x80): Point for Team 2 (Right / Red)
//   Double Click (Within 380ms): UNDO the previous point / game / set!
//
// Physical LED Chain & Wiring Order (136 LEDs Total):
//   1. Digit 0 (Team 1 Tens):            28 LEDs (0..27)
//   2. Digit 1 (Team 1 Ones):            28 LEDs (28..55)
//   3. Games & Sets Indicator Module:    24 LEDs (56..79)
//      - Left Column (Team 1, Bottom to Top):
//        * LEDs 56..64 (Indices 0..8):   Team 1 Games (G1..G9, bottom to top)
//        * LED 65      (Index 9):        Blank Spacer Gap (Always OFF)
//        * LEDs 66..67 (Indices 10..11): Team 1 Sets (S1, S2, bottom to top)
//      - Right Column (Team 2, Top to Bottom):
//        * LEDs 68..69 (Indices 12..13): Team 2 Sets (S2=top, S1=lower)
//        * LED 70      (Index 14):       Blank Spacer Gap (Always OFF)
//        * LEDs 71..79 (Indices 15..23): Team 2 Games (G9=top down to G1=bottom)
//   4. Digit 2 (Team 2 Tens):            28 LEDs (80..107)
//   5. Digit 3 (Team 2 Ones):            28 LEDs (108..135)
//
// Each 7-Segment Digit has 7 segments * 4 LEDs = 28 LEDs:
//   Segment 0: BL (Bottom-Left)  -> 0..3
//   Segment 1: B  (Bottom)       -> 4..7
//   Segment 2: BR (Bottom-Right) -> 8..11
//   Segment 3: M  (Middle)       -> 12..15
//   Segment 4: TL (Top-Left)     -> 16..19
//   Segment 5: T  (Top)          -> 20..23
//   Segment 6: TR (Top-Right)    -> 24..27
// ==============================================================================

// Standard C/C++ includes
#include <stdint.h>
#include <Arduino.h>
#include <Adafruit_NeoPixel.h>
#include <ThreeWire.h>
#include <RtcDS1302.h>
#include <NimBLEDevice.h>
#include "esp_mac.h"
extern "C" void ble_svc_gatt_changed(uint16_t start_handle, uint16_t end_handle);
#include <RtcDS3231.h>
#include <Preferences.h>
#include "ble_fota.h"
#if defined(ESP32)
  #include "driver/gpio.h"
#endif
#include <vector>
#include <string>

extern "C" void esp_brownout_disable(void);

// ==============================================================================
// Hardware Configuration (ESP32-C3 SuperMini)
// ==============================================================================
#define LED_PIN           2      // WS2813 Data Pin on ESP32-C3 SuperMini (GPIO 2, Hardware SPI MOSI)
#define ONBOARD_LED_PIN   8      // ESP32-C3 SuperMini LED (GPIO 8, Active LOW)
#define DS1302_CLK_PIN    4      // RTC SCLK -> GPIO 4
#define DS1302_DAT_PIN    5      // RTC DAT / IO -> GPIO 5
#define DS1302_RST_PIN    3      // RTC RST / CE -> GPIO 3

#define NUM_DIGITS        4      // 4 Digits total (2 for Team 1, 2 for Team 2)
#define LEDS_PER_SEGMENT  4      // 4 LEDs per segment
#define LEDS_PER_DIGIT    28     // 7 segments * 4 LEDs = 28 LEDs per digit
#define GAMES_SETS_LEDS   24     // 2 columns * 12 LEDs for Games & Sets Module
#define NUMPIXELS         (NUM_DIGITS * LEDS_PER_DIGIT + GAMES_SETS_LEDS) // 136 LEDs total
#define BRIGHTNESS        180    // LED brightness (0 - 255)

// ==============================================================================
// Padel & Match Scoring Engine State
// ==============================================================================
enum PadelPoint {
  POINT_0 = 0,   // " 0"
  POINT_15 = 1,  // "15"
  POINT_30 = 2,  // "30"
  POINT_40 = 3,  // "40"
  POINT_AD = 4   // "Ad"
};

struct ScoreState {
  PadelPoint p1;
  PadelPoint p2;
  int games1;
  int games2;
  int sets1;
  int sets2;
  bool matchWon;
  int s1g1, s1g2;
  int s2g1, s2g2;
  int s3g1, s3g2;
  int setsPlayed;
  bool inTb;
  int tb1, tb2;
  bool betweenGames;
  bool betweenSets;
  int compSetG1, compSetG2;
  bool courtInverted;
  int server;
  int tbFirstSrv;
  int setFirstSrv;
};

#define SCORE_HISTORY_DEPTH 30
ScoreState scoreHistory[SCORE_HISTORY_DEPTH];
int historyCount = 0;

PadelPoint team1Point = POINT_0;
PadelPoint team2Point = POINT_0;
int team1Games = 0;
int team2Games = 0;
int team1Sets = 0;
int team2Sets = 0;
bool matchWon = false;
bool betweenGames = false;
bool betweenSets = false;
int completedSetGames1 = 0;
int completedSetGames2 = 0;

// Match Rules Configuration (Persisted in NVS Flash)
bool cfgGoldenPoint = false; // false = Advantage (Ad-40), true = Punto de Oro (Deciding point)
int  cfgGamesPerSet = 6;     // 6 = Standard 6 games, 9 = Pro set
int  cfgSetsToWin   = 2;     // 1 = 1 set match, 2 = Best of 3 sets
bool cfgTiebreak    = true;  // true = Tiebreak at 6-6 (or 8-8)

// Tiebreak State
bool inTiebreak = false;
int tiebreakPoints1 = 0;
int tiebreakPoints2 = 0;

// Service Tracking (1 = Team 1 Left/Blue, 2 = Team 2 Right/Red)
int currentServer = 1;
int tbFirstServer = 1;
int setFirstServer = 1; // Team serving Game 1 of current set
uint8_t cfgServeIndicatorMode = 0; // 0=Standard (Bottom 0), 1=Player Top/Bottom 0, 2=Player L/R, 3=Off

int getTiebreakCurrentServer() {
  int tot = tiebreakPoints1 + tiebreakPoints2;
  if (tot == 0) return tbFirstServer;
  int pair = (tot - 1) / 2;
  return (pair % 2 == 0) ? (tbFirstServer == 1 ? 2 : 1) : tbFirstServer;
}

int getTiebreakServeCount() {
  int tot = tiebreakPoints1 + tiebreakPoints2;
  if (tot == 0) return 1;
  return ((tot - 1) % 2) + 1; // 1 or 2
}

bool isAtMatchStart() {
  return (team1Point == POINT_0 && team2Point == POINT_0 &&
          team1Games == 0 && team2Games == 0 &&
          team1Sets == 0 && team2Sets == 0 && !matchWon && !inTiebreak);
}

// Historical set games tracking for match summary
int set1Games1 = 0, set1Games2 = 0;
int set2Games1 = 0, set2Games2 = 0;
int set3Games1 = 0, set3Games2 = 0;
int totalSetsPlayed = 0;

enum MatchWonPhase {
  MATCH_PHASE_NONE,
  MATCH_PHASE_SPEL,
  MATCH_PHASE_SET_SCORES
};
MatchWonPhase matchWonPhase = MATCH_PHASE_NONE;
uint32_t matchWonStartTime = 0;

// Progression:
//   0 games (0-0): Normal (false)
//   1 game  (1-0): Swapped (true)   <- Swapped on 1st game (uneven)
//   2 games (1-1): Swapped (true)   <- No change! (even)
//   3 games (2-1): Normal (false)   <- Swapped on 3rd game (uneven)
//   4 games (4-0): Normal (false)   <- No change! (even)
//   5 games (3-2): Swapped (true)   <- Swapped on 5th game (uneven)
//   9 games (5-4): Swapped (true)   <- Swapped on 9th game (uneven)
bool courtSideInverted = false;
bool currentCourtSwapped = false;
inline bool isCourtSwapped() {
  bool standardSwap = false;
  if (inTiebreak) {
    int tbSum = tiebreakPoints1 + tiebreakPoints2;
    int totalGames = team1Games + team2Games;
    bool baseSwapped = ((totalGames + 1) / 2) % 2 == 1;
    // Tiebreak court ends swap every 6 points (6, 12, 18...)
    bool tbSwap = (tbSum / 6) % 2 == 1;
    standardSwap = baseSwapped ^ tbSwap;
  } else {
    int totalGames = team1Games + team2Games;
    standardSwap = ((totalGames + 1) / 2) % 2 == 1;
  }
  return standardSwap ^ courtSideInverted;
}

bool triggerGameWonAnimation  = false;
bool triggerSetWonAnimation   = false;
bool triggerMatchWonAnimation = false;
bool triggerTiebreakIntroAnimation = false;
uint32_t tiebreakIntroStartTime = 0;
int winningTeam = 0;
bool triggerUndoAction = false;
bool scoreNeedsUpdate = true;
bool showingSettingsInfo = true; // Kept on screen until first score is increased by remote, app, or watch
// Mode State Machine & Inactivity Idle Timer
enum DisplayMode {
  MODE_CLOCK,
  MODE_SCOREBOARD,
  MODE_COUNTER
};
DisplayMode currentMode = MODE_CLOCK; // Panel starts in Clock Mode on boot!

enum CounterSubMode {
  CTR_SINGLE_UP   = 1, // Mode 1: 0 -> 9999 count up
  CTR_SINGLE_DOWN = 2, // Mode 2: Target -> 0 countdown
  CTR_DUAL_UP     = 3, // Mode 3: 2 counters (0-59s on digits, minutes on Games&Sets LEDs)
  CTR_DUAL_DOWN   = 4  // Mode 4: 2 countdowns (MM:SS, minutes on Games&Sets LEDs)
};

struct CounterState {
  CounterSubMode subMode = CTR_SINGLE_UP;
  bool running1 = false;
  bool running2 = false;

  // Mode 1: 0 -> 9999
  int32_t countUpVal = 0;

  // Mode 2: Countdown from target
  int32_t countdownTarget = 100;
  int32_t countdownVal = 100;

  // Mode 3: Dual Count-Up (0-59s + Mins)
  int dualUpSec1 = 0, dualUpMin1 = 0;
  int dualUpSec2 = 0, dualUpMin2 = 0;

  // Mode 4: Dual Countdown (MM:SS)
  int dualDownTargetMin1 = 5, dualDownTargetSec1 = 0;
  int dualDownMin1 = 5, dualDownSec1 = 0;
  int dualDownTargetMin2 = 3, dualDownTargetSec2 = 0;
  int dualDownMin2 = 3, dualDownSec2 = 0;

  // Colors
  uint32_t color1 = 0x0000FF; // Team 1 Blue (0, 0, 255)
  uint32_t color2 = 0xFF0000; // Team 2 Red (255, 0, 0)
  uint32_t colorSingle = 0x0000FF; // Single counter color (Blue 0, 0, 255)

  // Timing
  uint32_t lastTickMs1 = 0;
  uint32_t lastTickMs2 = 0;

  // Completion alert animation
  bool alertActive = false;
  uint32_t alertStartMs = 0;
  bool finished1 = false;
  bool finished2 = false;
};
CounterState counterState;

void notifyCounterState();
void renderCounterDisplay();
void handleCounterTick();
bool counterNeedsUpdate = true;
uint32_t lastCounterRender = 0;
uint32_t lastActivityTime = 0;
uint8_t  cfgBrightness    = 88;              // LED brightness (0 - 125 safe range)
uint32_t cfgIdleTimeoutMs = 5 * 60 * 1000;   // Inactivity timeout in ms (0 = Never)
uint8_t  cfgClockR        = 0;               // Clock Digit Color: Red component (Default Pure Green #00FF00)
uint8_t  cfgClockG        = 255;             // Clock Digit Color: Green component
uint8_t  cfgClockB        = 0;               // Clock Digit Color: Blue component
uint32_t cfgClockColor    = 0;               // Cached packed NeoPixel color
uint8_t  cfgLedLayout     = 0;               // Hardware LED Layout: 0=136 (Sets&Match), 1=114 (4Dig+Colon), 2=112 (4Dig Direct)

// RTC & Clock State
ThreeWire rtcWire(DS1302_DAT_PIN, DS1302_CLK_PIN, DS1302_RST_PIN);
RtcDS1302<ThreeWire> Rtc(rtcWire);
bool rtcAvailable = false;
int curHour   = 12;
int curMinute = 0;
int curSecond = 0;
uint32_t lastInternalTick = 0;

// Watch BLE GATT Server Definitions
#define WATCH_SERVICE_UUID        "4fafc201-1fb5-459e-8fcc-c5c9c331914b"
#define WATCH_CHARACTERISTIC_UUID "beb5483e-36e1-4688-b7f5-ea07361b26a8"
NimBLECharacteristic* pWatchCharacteristic = nullptr;
void notifyWatchScore();

// Remote interaction tracking
enum RemoteButton { BUTTON_NONE, BUTTON_BIG, BUTTON_SMALL };
void handleCounterRemoteButton(RemoteButton btn, bool isDoubleClick);
volatile RemoteButton lastPressedButton = BUTTON_NONE;
volatile uint32_t lastPressTime = 0;
volatile bool pendingSingleClick = false;

// Long press detection (>= 1500ms held = trigger SWAP)
#define LONG_PRESS_MS 1500
volatile uint32_t buttonDownTime = 0;     // millis() when button was first pressed
volatile bool     buttonIsDown = false;   // true while physical button is held
volatile bool     longPressConsumed = false; // prevents single-click firing after a long press
bool triggerSwapAction = false;           // set true to trigger swap in main loop

// BLE Central State & Persistent Pairing
Preferences prefs;
String savedRemoteMac = "";
NimBLEAddress targetAddress;
bool hasTarget = false;
bool doConnect = false;
bool connected = false;
bool doScan = true;

// Hardware Instances
Adafruit_NeoPixel pixels(NUMPIXELS, LED_PIN, NEO_GRB + NEO_KHZ800);

// Hardware power governor & brightness manager (0-50% scale: max 125)
inline void updateLedBrightness(uint8_t brt) {
  if (brt > 125) brt = 125;
  cfgBrightness = brt;
  pixels.setBrightness(brt);
}

// ==============================================================================
// 7-Segment Font Table
// Segment Order per Digit:
//   [0] BL (Bottom-Left)
//   [1] B  (Bottom)
//   [2] BR (Bottom-Right)
//   [3] M  (Middle)
//   [4] TL (Top-Left)
//   [5] T  (Top)
//   [6] TR (Top-Right)
// ==============================================================================
#define DIGIT_BLANK        10
#define DIGIT_SERVE_BOTTOM 16  // Lower "0" (BL, B, BR, M)
#define DIGIT_SERVE_TOP    17  // Upper "0" (TL, T, TR, M)
#define DIGIT_SERVE_L      18  // Uppercase 'L' (BL, B, TL)
#define DIGIT_SERVE_R      19  // Lowercase 'r' (BL, M)
#define DIGIT_SERVE        DIGIT_SERVE_BOTTOM
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
void loop() {
  if (BleFota::isUpdating()) {
    delay(100);
    return;
  }

  updateClockTime();

  // Check Inactivity Idle Timer:
  // If in Scoreboard Mode and inactivity timer expired, return to Clock Mode!
  // Note: While holding between games/sets or match won, keep score visible on the board!
  if (currentMode == MODE_SCOREBOARD && cfgIdleTimeoutMs > 0 && !betweenGames && !matchWon && !triggerTiebreakIntroAnimation) {
    if (millis() - lastActivityTime >= cfgIdleTimeoutMs) {
      Serial.println("[MODE] Inactivity timeout -> Automatically switching to Clock Mode");
      currentMode = MODE_CLOCK;
    }
  }

  // If in Clock Mode, render clock display and blinking colon
  if (currentMode == MODE_CLOCK) {
    static uint32_t lastClockRender = 0;
    if (millis() - lastClockRender >= 80) { // 80ms refresh for smooth 500ms colon blink
      lastClockRender = millis();
      renderClock();
    }
  }

  // If in Counter Mode, process ticks and render counter display
  if (currentMode == MODE_COUNTER) {
    if (counterState.running1 || counterState.running2) {
      lastActivityTime = millis();
    }
    handleCounterTick();
    if (counterNeedsUpdate || (millis() - lastCounterRender >= 80)) {
      lastCounterRender = millis();
      renderCounterDisplay();
      counterNeedsUpdate = false;
    }
  }

  if (doConnect && hasTarget) {
    doConnect = false;
    if (!connectToRemote()) {
      Serial.println("[BLE] Retrying scan in 300ms...");
      hasTarget = false;
      delay(300);
      doScan = true;
    }
  }

  if (doScan && !connected) {
    doScan = false;
    hasTarget = false;
    setStatusLed(0, 0, 50); // Blue: Scanning
    Serial.println("[BLE] Starting background scan for remote...");
    NimBLEScan* pScan = NimBLEDevice::getScan();
    pScan->clearResults();
    pScan->start(0, nullptr, false);
  }

  // Gentle onboard LED blink while awaiting Bluetooth connection
  static uint32_t lastScanBlink = 0;
  static bool scanBlinkState = false;
  if (!connected && millis() - lastScanBlink > 500) {
    lastScanBlink = millis();
    scanBlinkState = !scanBlinkState;
    digitalWrite(ONBOARD_LED_PIN, scanBlinkState ? LOW : HIGH);
  }

  // ── Long-press proactive check (fires while button is still held) ─────────
  // If a button has been held for >= LONG_PRESS_MS without being released yet,
  // consume it as a swap now (don't wait for release). Cancel any pending single-click.
  if (buttonIsDown && !longPressConsumed && (millis() - buttonDownTime >= LONG_PRESS_MS)) {
    longPressConsumed = true;     // suppress the eventual release from adding a point
    pendingSingleClick = false;   // cancel any in-flight single-click
    triggerSwapAction = true;
    Serial.printf("[LONG-PRESS] Button held %lums -> triggering SWAP\n",
                  (unsigned long)(millis() - buttonDownTime));
  }

  // Handle single-click expiration (380ms timeout)
  if (pendingSingleClick && (millis() - lastPressTime >= 380)) {
    pendingSingleClick = false;

    if (currentMode == MODE_COUNTER) {
      handleCounterRemoteButton(lastPressedButton, false);
    } else {
      if (inTiebreak && triggerTiebreakIntroAnimation) {
        triggerTiebreakIntroAnimation = false;
        betweenGames = false;
        betweenSets = false;
        scoreNeedsUpdate = true;
        notifyWatchScore();
        lastActivityTime = millis();
        Serial.println("[TIEBREAK] Button Pressed -> Dismissed tb screen, showing 0/0 with serve indication");
      } else {
        const char* pointNames[] = { " 0", "15", "30", "40", "Ad" };
        if (lastPressedButton == BUTTON_BIG) {
          addPadelPoint(1);
          Serial.printf("[BUTTON] Big Button -> Team 1 Point! Score: %s - %s (Games: %d-%d | Sets: %d-%d)\n",
                        pointNames[team1Point], pointNames[team2Point], team1Games, team2Games, team1Sets, team2Sets);
          if (inTiebreak) {
            bool newSwapped = isCourtSwapped();
            if (newSwapped != currentCourtSwapped && !triggerGameWonAnimation && !triggerSetWonAnimation && !triggerMatchWonAnimation) {
              animateCourtSideSwap(newSwapped);
              currentCourtSwapped = newSwapped;
            }
          }
          lastActivityTime = millis();
          scoreNeedsUpdate = true;
        } else if (lastPressedButton == BUTTON_SMALL) {
          addPadelPoint(2);
          Serial.printf("[BUTTON] Small Button -> Team 2 Point! Score: %s - %s (Games: %d-%d | Sets: %d-%d)\n",
                        pointNames[team1Point], pointNames[team2Point], team1Games, team2Games, team1Sets, team2Sets);
          if (inTiebreak) {
            bool newSwapped = isCourtSwapped();
            if (newSwapped != currentCourtSwapped && !triggerGameWonAnimation && !triggerSetWonAnimation && !triggerMatchWonAnimation) {
              animateCourtSideSwap(newSwapped);
              currentCourtSwapped = newSwapped;
            }
          }
          lastActivityTime = millis();
          scoreNeedsUpdate = true;
        }
      }
    }
  }

  // Handle Double-click UNDO
  if (triggerUndoAction) {
    triggerUndoAction = false;
    lastActivityTime = millis();
    if (currentMode == MODE_COUNTER) {
      handleCounterRemoteButton(lastPressedButton, true);
    } else {
      if (isAtMatchStart()) {
        currentServer = (currentServer == 1) ? 2 : 1;
        tbFirstServer = currentServer;
        setFirstServer = currentServer;
        showingSettingsInfo = false; // exit settings splash if shown
        Serial.printf("[BUTTON] Double Click at 0-0 -> Toggled First Server! Team %d is now serving first.\n", currentServer);
        // Quick flash on middle module
        drawGamesAndSets(0, 0, 0, 0);
        showPixelsSafe();
        delay(60);
        scoreNeedsUpdate = true;
        notifyWatchScore();
      } else if (undoScoreState()) {
        const char* pointNames[] = { " 0", "15", "30", "40", "Ad" };
        Serial.printf("[BUTTON] Double Click -> UNDO! Restored: %s - %s (Games: %d-%d | Sets: %d-%d)\n",
                      pointNames[team1Point], pointNames[team2Point], team1Games, team2Games, team1Sets, team2Sets);
        // Quick flash off of the Games/Sets module to confirm undo action
        drawGamesAndSets(0, 0, 0, 0);
        showPixelsSafe();
        delay(80);

        bool newSwapped = isCourtSwapped();
        if (newSwapped != currentCourtSwapped) {
          Serial.printf("[PADEL] Court side switch on Undo! (%s -> %s)\n",
                        currentCourtSwapped ? "Swapped" : "Normal",
                        newSwapped ? "Swapped" : "Normal");
          animateCourtSideSwap(newSwapped);
          currentCourtSwapped = newSwapped;
        }

        notifyWatchScore();
        scoreNeedsUpdate = true;
      } else {
        Serial.println("[BUTTON] Undo pressed, but no history available");
      }
    }
  }

  // Handle Long-press:
  // - In Clock Mode: Long press goes back to Scoring (Scoreboard Mode).
  // - In Scoreboard Mode during the 1st game (0-0 games/sets): Long press switches team positions (SWAP).
  // - In Scoreboard Mode after the 1st game: Long press toggles to Clock Mode.
  if (triggerSwapAction) {
    triggerSwapAction = false;
    lastActivityTime = millis();
    if (currentMode == MODE_CLOCK) {
      Serial.println("[LONG-PRESS] Clock Mode -> Switching back to Scoring (Scoreboard Mode)!");
      currentMode = MODE_SCOREBOARD;
      scoreNeedsUpdate = true;
      notifyWatchScore();
    } else if (currentMode == MODE_SCOREBOARD) {
      bool isFirstGame = (team1Games == 0 && team2Games == 0 && team1Sets == 0 && team2Sets == 0);
      if (isFirstGame) {
        Serial.println("[LONG-PRESS] 1st Game -> Switching team positions (SWAP)!");
        courtSideInverted = !courtSideInverted;
        currentCourtSwapped = isCourtSwapped();
        animateCourtSideSwap(currentCourtSwapped);
        notifyWatchScore();
        scoreNeedsUpdate = true;
      } else {
        Serial.println("[LONG-PRESS] After 1st Game -> Switching to Clock Mode!");
        currentMode = MODE_CLOCK;
        renderClock();
      }
    }
  }

  // 1. Handle Game Won Animation (3 flashes of the winning team's side)
  if (triggerGameWonAnimation) {
    triggerGameWonAnimation = false;
    lastActivityTime = millis();
    uint32_t winColor = (winningTeam == 1) ? pixels.Color(0, 0, 255) : pixels.Color(255, 0, 0);
    Serial.printf("[PADEL] ★ GAME WON by Team %d! Current Games: %d - %d (Sets: %d - %d)\n",
                  winningTeam, team1Games, team2Games, team1Sets, team2Sets);
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

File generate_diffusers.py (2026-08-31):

import struct
import math
import os
import zipfile

def create_segment_polygon(length, width):
    """
    Returns 2D polygon vertices for a 45-degree chamfered 7-segment shape.
    Centered at (0, 0).
    """
    half_l = length / 2.0
    half_w = width / 2.0
    
    # 6-sided hexagon polygon
    return [
        (-half_l, 0.0),
        (-half_l + half_w, -half_w),
        (half_l - half_w, -half_w),
        (half_l, 0.0),
        (half_l - half_w, half_w),
        (-half_l + half_w, half_w)
    ]

def transform_polygon(poly, tx, ty, rotate_deg=0):
    rad = math.radians(rotate_deg)
    cos_a = math.cos(rad)
    sin_a = math.sin(rad)
    
    transformed = []
    for x, y in poly:
        # Rotate
        rx = x * cos_a - y * sin_a
        ry = x * sin_a + y * cos_a
        # Translate
        transformed.append((rx + tx, ry + ty))
    return transformed

def triangulate_polygon_prism(poly_2d, z_min, z_max):
    """
    Triangulates a 2D convex/simple polygon extruded from z_min to z_max.
    Returns list of triangles, each triangle is ((x1,y1,z1), (x2,y2,z2), (x3,y3,z3)).
    """
    triangles = []
    n = len(poly_2d)
    
    # Bottom face (z_min, normal pointing down)
    # Fan triangulation from vertex 0
    for i in range(1, n - 1):
        triangles.append((
            (poly_2d[0][0], poly_2d[0][1], z_min),
            (poly_2d[i+1][0], poly_2d[i+1][1], z_min),
            (poly_2d[i][0], poly_2d[i][1], z_min)
        ))
        
    # Top face (z_max, normal pointing up)
    # Fan triangulation from vertex 0
    for i in range(1, n - 1):
        triangles.append((
            (poly_2d[0][0], poly_2d[0][1], z_max),
            (poly_2d[i][0], poly_2d[i][1], z_max),
            (poly_2d[i+1][0], poly_2d[i+1][1], z_max)
        ))
        
    # Side quads (2 triangles per segment)
    for i in range(n):
        next_i = (i + 1) % n
        p1 = poly_2d[i]
        p2 = poly_2d[next_i]
        
        # Tri 1: (p1_bot, p2_bot, p2_top)
        triangles.append((
            (p1[0], p1[1], z_min),
            (p2[0], p2[1], z_min),
            (p2[0], p2[1], z_max)
        ))
        # Tri 2: (p1_bot, p2_top, p1_top)
        triangles.append((
            (p1[0], p1[1], z_min),
            (p2[0], p2[1], z_max),
            (p1[0], p1[1], z_max)
        ))
        
    return triangles

def write_binary_stl(filepath, triangles):
    header = b"Generated by Antigravity - 7Segment Dual-Layer Diffuser" + b"\x00" * 25
    header = header[:80]
    
    with open(filepath, "wb") as f:
        f.write(header)
        f.write(struct.pack("<I", len(triangles)))
        
        for tri in triangles:
            p1, p2, p3 = tri
            # Calculate normal
            u = (p2[0]-p1[0], p2[1]-p1[1], p2[2]-p1[2])
            v = (p3[0]-p1[0], p3[1]-p1[1], p3[2]-p1[2])
            nx = u[1]*v[2] - u[2]*v[1]
            ny = u[2]*v[0] - u[0]*v[2]
            nz = u[0]*v[1] - u[1]*v[0]
            norm = math.sqrt(nx*nx + ny*ny + nz*nz)
            if norm > 1e-9:
                nx /= norm
                ny /= norm
                nz /= norm
            else:
                nx, ny, nz = 0.0, 0.0, 1.0
                
            f.write(struct.pack("<fff", nx, ny, nz))
            f.write(struct.pack("<fff", p1[0], p1[1], p1[2]))
            f.write(struct.pack("<fff", p2[0], p2[1], p2[2]))
            f.write(struct.pack("<fff", p3[0], p3[1], p3[2]))
            f.write(struct.pack("<H", 0))

def generate_7segment_polygons():
    pitch_x = 92.0
    pitch_y_top = 92.0
    pitch_y_bot = 92.0
    
    total_seg_w = 18.0
    total_seg_l_x = 104.0
    total_seg_l_y_top = 104.0
    total_seg_l_y_bot = 117.0
    
    poly_horiz_top = create_segment_polygon(total_seg_l_x, total_seg_w)
    poly_horiz_mid = create_segment_polygon(total_seg_l_x, total_seg_w)
    poly_horiz_bot = create_segment_polygon(total_seg_l_x, total_seg_w)
    
    poly_vert_top = create_segment_polygon(total_seg_l_y_top, total_seg_w)
    poly_vert_bot = create_segment_polygon(total_seg_l_y_bot, total_seg_w)
    
    all_polys = [
        # Segment A (Top horizontal)
        transform_polygon(poly_horiz_top, 0, pitch_y_top, 0),
        # Segment B (Top-Right vertical)
        transform_polygon(poly_vert_top, pitch_x/2, pitch_y_top/2, 90),
        # Segment C (Bottom-Right vertical)
        transform_polygon(poly_vert_bot, pitch_x/2, -pitch_y_bot/2, 90),
        # Segment D (Bottom horizontal)
        transform_polygon(poly_horiz_bot, 0, -pitch_y_bot, 0),
        # Segment E (Bottom-Left vertical)
        transform_polygon(poly_vert_bot, -pitch_x/2, -pitch_y_bot/2, 90),
        # Segment F (Top-Left vertical)
        transform_polygon(poly_vert_top, -pitch_x/2, pitch_y_top/2, 90),
        # Segment G (Middle horizontal)
        transform_polygon(poly_horiz_mid, 0, 0, 0),
    ]
    return all_polys

def main():
    out_dir = r"c:\Users\geert\Documents\Github\7segment\3d_models"
    os.makedirs(out_dir, exist_ok=True)
    
    # 1. Single segment test pieces (Length 104mm, Width 18mm)
    single_poly = [create_segment_polygon(104.0, 18.0)]
    
    # Layer 1: White (0.0 to 0.2 mm)
    single_white_tris = []
    for p in single_poly:
        single_white_tris.extend(triangulate_polygon_prism(p, 0.0, 0.2))
    write_binary_stl(os.path.join(out_dir, "single_segment_0.2mm_layer1_WHITE.stl"), single_white_tris)
    
    # Layer 2: Transparent (0.2 to 0.8 mm)
    single_transp_tris = []
    for p in single_poly:
        single_transp_tris.extend(triangulate_polygon_prism(p, 0.2, 0.8))
    write_binary_stl(os.path.join(out_dir, "single_segment_0.6mm_layer2_TRANSPARENT.stl"), single_transp_tris)
    
    # Single Solid STL (0.0 to 0.8 mm)
    single_solid_tris = []
    for p in single_poly:
        single_solid_tris.extend(triangulate_polygon_prism(p, 0.0, 0.8))
    write_binary_stl(os.path.join(out_dir, "single_segment_0.8mm_SOLID.stl"), single_solid_tris)
    
    # 2. Full 7-Segment Diffuser
    seven_polys = generate_7segment_polygons()
    
    # Layer 1: White (0.0 to 0.2 mm)
    seven_white_tris = []
    for p in seven_polys:
        seven_white_tris.extend(triangulate_polygon_prism(p, 0.0, 0.2))
    write_binary_stl(os.path.join(out_dir, "7segment_diffuser_0.2mm_layer1_WHITE.stl"), seven_white_tris)
    
    # Layer 2: Transparent (0.2 to 0.8 mm)
    seven_transp_tris = []
    for p in seven_polys:
        seven_transp_tris.extend(triangulate_polygon_prism(p, 0.2, 0.8))
    write_binary_stl(os.path.join(out_dir, "7segment_diffuser_0.6mm_layer2_TRANSPARENT.stl"), seven_transp_tris)
    
    # Full Solid STL (0.0 to 0.8 mm)
    seven_solid_tris = []
    for p in seven_polys:
        seven_solid_tris.extend(triangulate_polygon_prism(p, 0.0, 0.8))
    write_binary_stl(os.path.join(out_dir, "7segment_diffuser_0.8mm_SOLID.stl"), seven_solid_tris)
    
    print("All STL files successfully created in:", out_dir)

if __name__ == "__main__":
    main()

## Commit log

2026-08-31 Mayor update
    [4digit_clock_preview.scad, 7segment.scad, 7segment_diffuser_0.2mm_layer1_WHITE.stl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]
2026-09-01 Update 4-digit padel scoreboard firmware with colon and sequential segment mapping
    [4digit_clock_preview.scad, 7segment_pogo.scad, 7segment_pogo_back.stl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]
2026-09-06 Multi updates
    [4digit_clock_preview.scad, 7segment.scad, 7segment_diffuser_0.2mm_layer1_WHITE.stl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]
2026-09-06 Reformat app for mobile screens with tabbed layout and large touch buttons
2026-09-07 update panel master
    [padel_battery_holder.scad, padel_battery_holder.stl, padel_hook.stl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]
2026-09-07 Fix BLE write race condition and characteristic properties for clock color
    [main_button_Setsandmatch.cpp]
2026-09-07 Fix brightness updating: restore backward-compatible CFG,BRT command, debounced slider, and display re-render
    [main_button_Setsandmatch.cpp]
2026-09-07 Remove Match Rules & Game Modes card from Wireless Firmware Flasher
2026-09-15 Updates of the 3D files
    [display_stand.scad, display_stand.stl, display_stand_cradle_pair.stl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]
2026-09-15 Fix WS2813 SPI DMA reset signal and locking cap geometry
    SPI DMA reset fix (main_button_Setsandmatch.cpp):
    - Encoded '0' bits (0x08 nibbles) produce 300ns HIGH pulses, not continuous
    LOW, so the 250 zero-byte trailing reset violated WS2813 >=280us LOW reset.
    - Fix: send only LED + dummy pixel data via SPI; rely on GPIO_PULLDOWN_ONLY
    (already configured) + 350us delayMicroseconds for the clean latch reset.
    - This removes the stale-latch artifact that caused the first LED to briefly
    show blue before correctly-colored segments appeared in clock mode.
    panel_thumbscrew.scad locking cap geometry fix:
    - Removed destructive 2.2mm center drill that severed the Philips cross
    into 4 floating,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
    [panel_thumbscrew.scad, panel_thumbscrew.stl]
2026-09-16 Sync CURRENT_APP_VERSION to 1.4.3 and fix persistent update prompt loop
2026-09-16 Update battery holder
    [padel_battery_holder.scad, padel_battery_holder.stl, padel_battery_holder_vesa.scad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]
2026-09-20 FW update switch teams
2026-09-20 Updated strap holder
    [remote_strap_holder.scad, remote_strap_holder.stl, remote_strap_holder_flat.stl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]
2026-09-22 swap fixed
    [test_short_sides.stl, test_short_sides3.stl, test_short_sides_flat.stl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]
2026-09-22 big screen
    [7segment_pogo.scad, 7segment_pogo_lader.stl, panel3_backplate_wpt.stl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]
2026-09-22 touch didn't move with scores
    [sw.js]
2026-09-23 REmove the save to panel button
2026-09-28 Quick Start Guide BT button
    [panel_seam_u_bracket.scad, panel_seam_u_bracket_set4_hook.stl, panel_seam_u_hook_bracket.stl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]
2026-09-29 Removed the panel leds selection
    [panel_seam_u_bracket.scad, panel_seam_u_hook_bracket_rear_eye.stl, panel_seam_u_hook_bracket_rear_eye_pair.stl]
2026-09-29 install app bug fix
    [sw.js]
2026-09-29 app update bug fixed
    [sw.js]
2026-09-29 Made de website
2026-09-29 Updates to avoid blue leds
    [main_button_Setsandmatch.cpp]
